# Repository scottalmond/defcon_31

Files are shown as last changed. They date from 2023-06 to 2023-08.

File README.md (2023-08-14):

# Space Pony Overview

This repo contains the project files for two Silly Add-On (SAO) Printed Circuit Boards (PCBs) for DEFCON 31.

## User Guide

Where to buy the units is explained here:

Bumper reel and general information (https://www.youtube.com/watch?v=0cRPfB8QzD0)

A summary of the key features and interfaces are documented in the following video:

Features and Interfaces (https://www.youtube.com/watch?v=cUO3zqiO3F0)

## Space Bits R Us

This is the team badge for those competing in the Hack-a-Sat competition.  These are exclusive badges for the team and not for general sale.

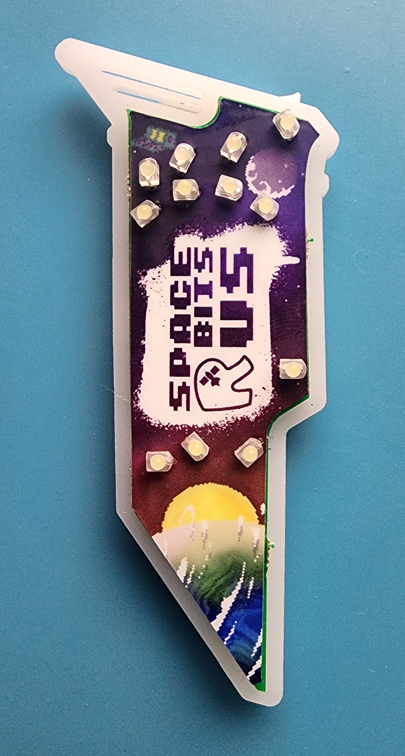
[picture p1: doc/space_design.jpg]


## Pony Circuit Board

- These badges present "My Little Pony Friendship is Magic" characters surrounded by LEDs.
- These badges are for sale, $20 per unit.  There are 11 unique designs.
- Each "Space Bits R Us" team member (identifiable because they are wearing the "Space Bits" badge described above) will have several units for sale.
- Visit the Hack-a-sat competition area immediately before, or immediately after competition each day to acquire one.
	- Specifically: ---before 10 AM Friday/Saturday---, after 8 PM Friday/Saturday, before Noon Sunday, or after 1:30 PM Sunday.
- Excess stickers were attached to colored acrylic for general distribution
	- Only white acrylic units have LEDs

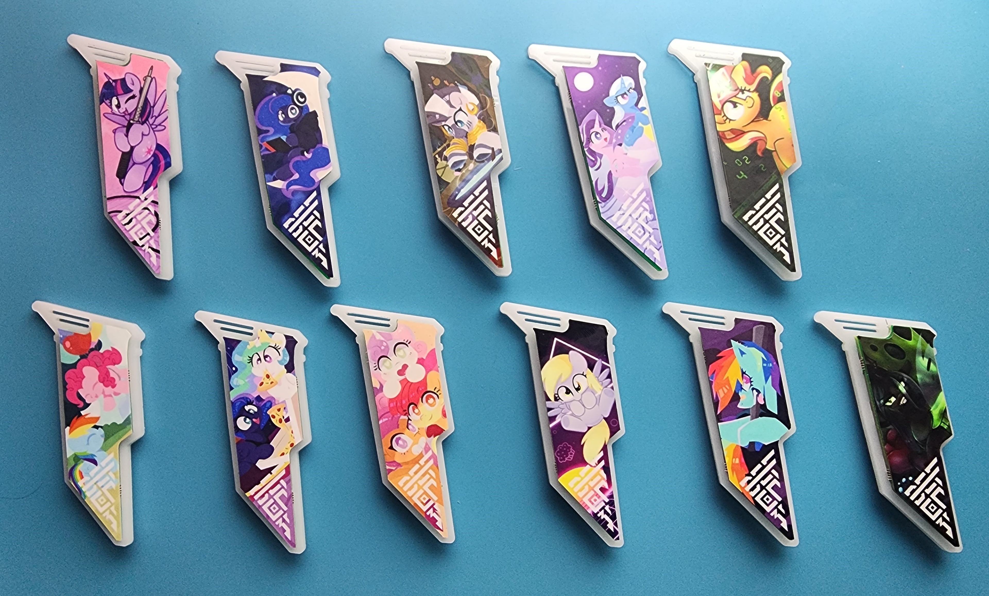
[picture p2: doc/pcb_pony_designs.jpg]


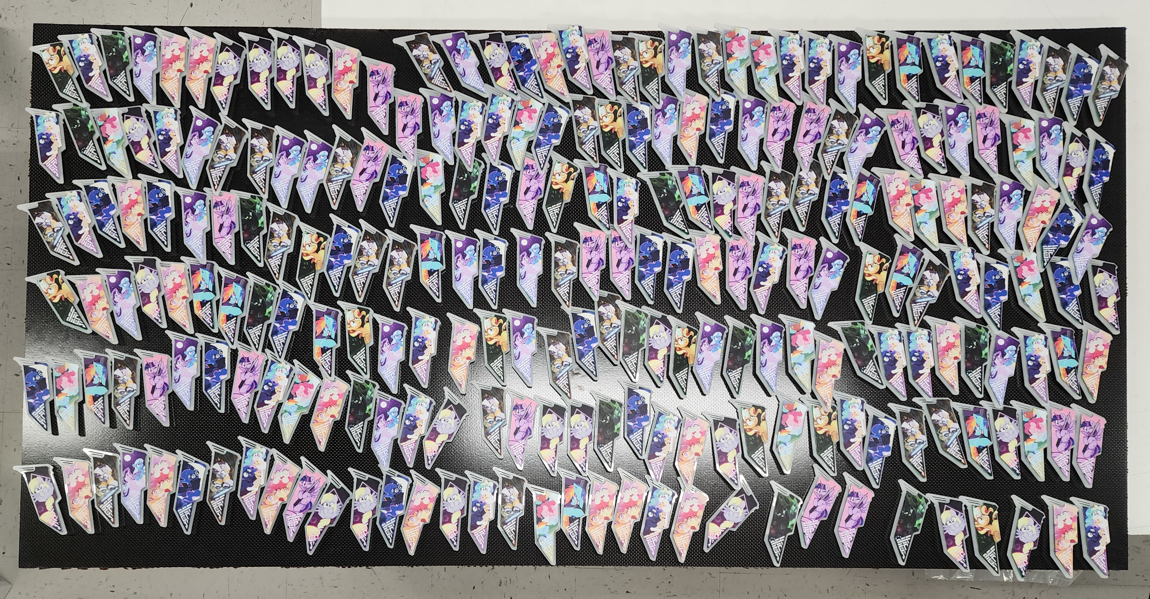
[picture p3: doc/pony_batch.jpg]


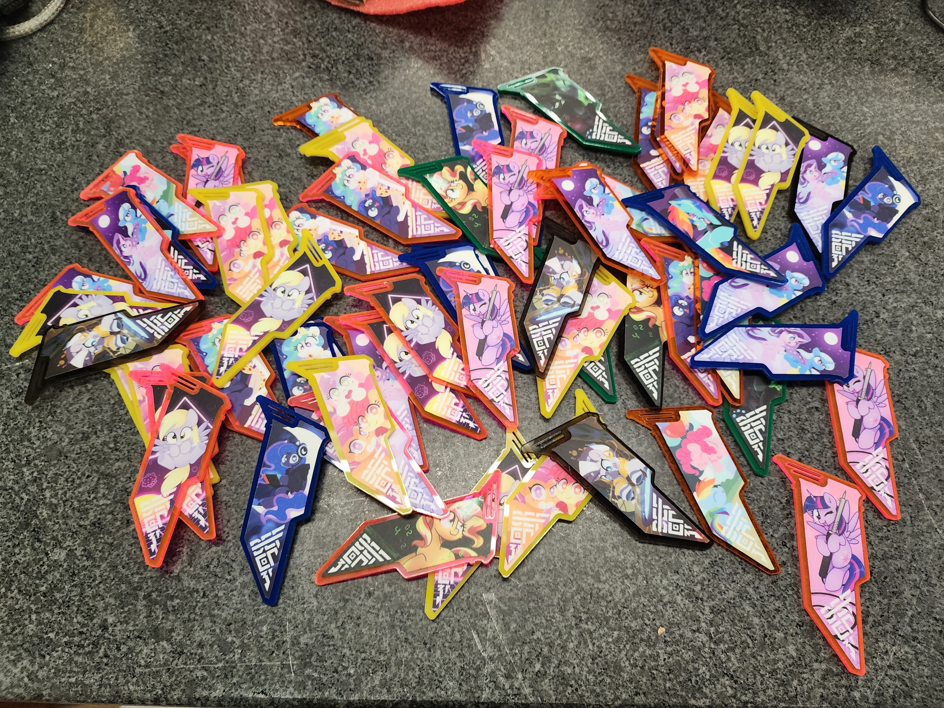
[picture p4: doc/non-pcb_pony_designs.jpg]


# Features

- STM8S003F3P6TR Processor
	- 8 kB Flash
	- 1 kB RAM
	- 128 B EEPROM
- Microphone
- 16 MHz clock, 10 ppm
- LiPo Battery
	- 40 mAh LIR2032 LiPo (Pony SAO)
		- ~2 hours battery life at max brightness
	- 500 mAh 502540 LiPo (Space Bits R Us SAO)
		- ~25 hours battery life at max brightness
- LiPo Charger
	- ~3 hours to charge from 3V to 4.2V
- Developer header
	- 5V charging input
	- ST SWIM Interface
	- 57600 MBaud UART
	- I2C
- SAO 4-pin header pads
	- Under BT1 (Pony SAO)
	- Under Acrylic (Space Bits R Us SAO)
- 10x RGB LEDs
- 12x White LEDs
	- Space Bits R Us SAO Only
- 1x Status LED
	- Green
		- 5V input is present
		- Battery is fully charged, if present
	- Green + Blue = Cyan
		- Battery Charging is Underway
	- Red
		- A user button is pressed, or UART terminal is active

# Schematic

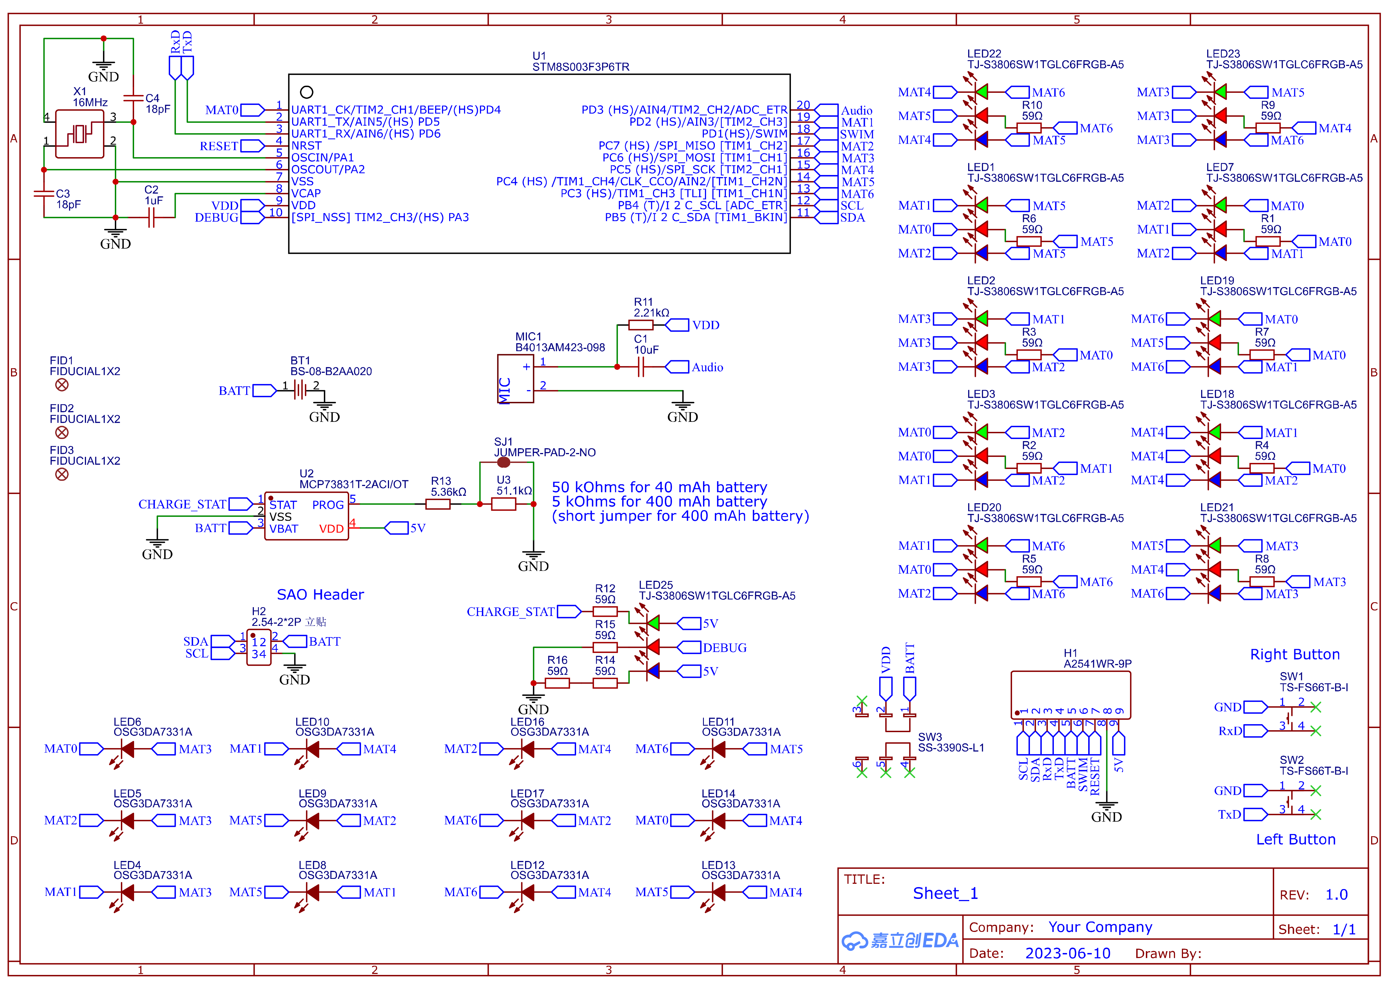
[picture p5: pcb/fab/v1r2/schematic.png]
DefCon31 v1r2


# Hardware

## Design

- Concept, Project Management, PCB Design, Software Architecture: [Scott Almond](https://github.com/scottalmond)
- Morse Code, Cyclone Game, Terminal Artwork: [Brian Wilkins](SpaceHamBrian@gmail.com)
- Pony & space artwork: [Sugar Morning](https://twitter.com/itssugarmorning)

## Fabrication & Tools

- PCB design in [EasyEDA](https://easyeda.com/); PCB/PCBA fabrication through [JLCPCB](https://jlcpcb.com/)
- Acrylic stock, 45% lighting white, 1/8" thick through [TAP Plastics](https://www.tapplastics.com/)
- Acrylic cutting in-house using a LC40 Dremel laser cutter
- Stickers fabricated by [Sticker Mule](https://www.stickermule.com/)
- Through-hole LEDs, batteries, and support hardware (protoboards, pogo pins, etc) purchased through [Aliexpress](https://www.aliexpress.us) vendors

# Eratta

- STM8 programming reference: https://hackaday.io/project/161239-stm8s-development-board
- STM8 programmer setup: https://circuitdigest.com/microcontroller-projects/getting-started-with-stm8s-using-stvd-and-cosmic-c-compiler
	- Including Cosmic C license request (allow 2 business days to get a key) ref. https://github.com/NevynUK/The-Way-of-the-Register
- How to fix git login: https://www.youtube.com/watch?v=EaN7TnD8RvM

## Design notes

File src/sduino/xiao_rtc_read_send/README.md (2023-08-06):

# SAMD21 Xiao Button Interface and DS3231 RTC Task

This Arduino code is designed to work with a SAMD21 Xiao microcontroller board, a Joystick Shield button interface, and a DS3231 Real-Time Clock (RTC) module. The code is intended to perform a specific task when the user presses a button on the Joystick Shield.

## Task Description

When the user presses the button on the Joystick Shield:

1. Turn on the on-board LED of the SAMD21 Xiao to indicate the start of the task.
2. Drive a digital output pin low to signal another board to go into developer mode.
3. Read the current time from the DS3231 RTC module and convert it to milliseconds since 8/5/2023 at midnight.
4. Create a time string in the format "t <milliseconds>\n" (e.g., "t 5649548\n").
5. Transmit the time string over UART (Serial) to the other board at a baud rate of 57600.
6. Optionally, introduce a small delay (100 milliseconds) to indicate the completion of the task.
7. Disable the relay by setting the digital output pin to an input mode (float the developer mode pin).
8. Turn off the on-board LED to signify the end of the task.

## Usage

1. Connect the Joystick Shield button interface and DS3231 RTC module to the appropriate pins on the SAMD21 Xiao board as described in the "Connections" section of this README.
2. Install the required `RTCLib` library in the Arduino IDE to work with the RTC module.
3. Upload the provided Arduino code (`main.ino`) to the SAMD21 Xiao using the Arduino IDE.
4. The code will run in an infinite loop, waiting for the button press. When the button is pressed, the specified tasks will be executed sequentially.

## Connections

### Joystick Shield Button Interface:

- Connect the GND (ground) pin of the Joystick Shield to any GND pin on the SAMD21 Xiao.
- Connect the VCC pin of the Joystick Shield to any 3.3V pin on the SAMD21 Xiao.
- Connect the signal (SIG) pin of the Joystick Shield to a digital input pin on the SAMD21 Xiao, for example, pin 2.

### DS3231 RTC Module:

- Connect the GND (ground) pin of the RTC module to any GND pin on the SAMD21 Xiao.
- Connect the VCC pin of the RTC module to any 3.3V pin on the SAMD21 Xiao.
- Connect the SDA pin of the RTC module to the I2C data pin (SDA) on the SAMD21 Xiao, usually pin A4.
- Connect the SCL pin of the RTC module to the I2C clock pin (SCL) on the SAMD21 Xiao, usually pin A5.

## Notes

- Replace `<outputPin>` in the code with the actual pin number you want to use for the developer mode signal.
- Ensure that the RTC module and Joystick Shield are connected properly to avoid any issues.
- The on-board LED will briefly illuminate during task execution, indicating that the task is in progress.

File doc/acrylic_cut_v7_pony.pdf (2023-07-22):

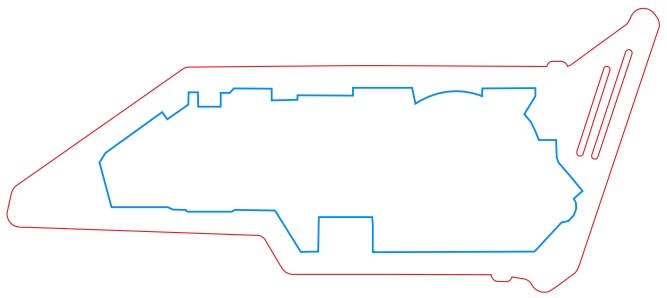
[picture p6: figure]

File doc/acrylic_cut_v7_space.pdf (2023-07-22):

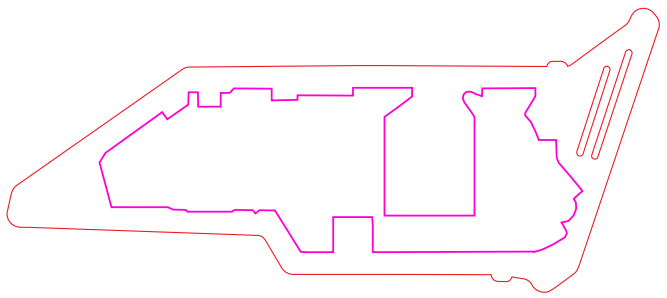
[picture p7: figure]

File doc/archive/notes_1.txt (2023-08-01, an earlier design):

void set_rgb(u8 led_index,u8 rgb_index,u8 brightness);// led_index[0-9], rgb_index[0-2], brightness[0-255]
void set_white(u8 led_index,u8 brightness);// led_index[0-11], brightness [0-255]
void set_debug(u8 brightness);
//void set_led_count(u8 led_count);//led_count [0-41] of non-zero illuminated RGB+White LEDs
void flush_leds(u8 led_count);//pushes the temprory values live to the periphreal
void reset_leds();//sets all rgb+white LEDs to 0 brightness
uint8_t get_audio();//sampling at 1-4 kHz, updating a state machine at 256 states (4-16 Hz updates)
//bool get_button(bool is_left);//return true if button is pressed.  does NOT perform de-bouncing
u32 millis();//returns a long value of the current time stamp (UNIX milliseconds since 1/1/1970)
bool delay(u16 milliseconds);//milliseconds to wait for.  returns true on success (completed wait operation).  returns false if wait was interrupted (ex. by button push)
bool is_space_bits();//returns true if the SAO is configered for the Space Bits team, otherwise returns false for the 
char readEEPROM(u8 address);//fetch value from EEPROM
void writeEPROM(u8 address,u8 value);//push value into EEPROM
bool is_button_pressed(bool is_left,bool is_short); //isButtonPressed(true,true); returns true if the left button is pressed for 0.05-2 seconds.  (true,false) returns true if left button has been pressed for >2 seconds.  so bool is_right=isButtonPressed(false,true) || isButtonPressed((false,false); is expected here
void clear_button_pressed(bool is_left,bool is_short); //call this after you consume/use or otherwise respond to a button press event
bool is_application_valid(); //when you do infinite while(true) loops, use this method for the "true" part.  I'll be polling for console UART content and timeouts here.  When there are external events, this method will return false and the submenu will exit up to the top level menu.

//UART:
//t # //get time with no parameters, set time with one decimal number.
//  u# //DEPRECITED, was going to used to correct sub-second clock drivt residual; assumed to be negliable and low-priority
//e # # //write to eeprom directly.  numbers are in human-readable DEC (not 0-255 in every char; this avoid issue with 10 being read as '\n')
//e # //read eeprom char at address
//h help (prints epprom status and current time)
//p ping (echo's UART commands sent to it: between 'p' character and \n)
//  s# system diagnostic (test all peripherals: blink leds, read audio and output to terminal: 1k samples).  diagnostic 0 is all leds and mic check.  diagnsotic 1 is current time (millis()/1000): the 10 LSB piped out to RGB LEDs
//l # # # //light up the given RGB led at the given brightness (0-9, 0-2, 0-255)
//w # # //light up the given white led at the given brightness (applicable to Space SAO only, others will have current leakage on red+green LEDs over non-populated part)
//a //prints the audio level continuosuly until a new line character is detected

//EEPROM:
//0 DEVELOPMENT
//1 TEST (sw revision id)
//2 Space Bits (1 for team, 0 for cute sales)
//3 DEVICE ID
//4-7 baseline start ms
//8-11 time base ms
//12 +/- 1 ms

//diagnostic menu: the LSB 10 bits of the current time (millis()/1000) are mapped to the RGB around the periphery.  When time is syncronized, across all badges, they all tick-tock in unison

void t()
{
	eeprom.write(4:7,UART.read());
	tms=0;
}

void u()
{
	u16 diff_residual=tms-UART.read();//how far off time-at-tone was from expectation
	long diff_baseline=UART.read()-eeprom.write(4:7);
	diff_baseline/=diff_residual;
	eepromt.write(8:11,diff_baseline<0?-diff_baseline:diff_baseline);//write positive number to flash
	eeprom.write(diff_baseline<0?-1:1);
}

#define RGB_LED_COUNT 9
#define WHITE_LED_COUNT 11

rules:
- for digital read/write, must use the methods above
- in order to use a variable, must declare at the beginning of a method
- types: int (signaed 16-bit), char/uint8_t unsigned 0-255, long (4-byte), bool

menus

sudo sode for audio:
void submenu_audio()
{
	u8 audio_level,led_index;
	audio_level=get_audio();
	reset_leds();
	for(led_index=0;led_index<RGB_LED_COUNT;led_index++)
	{
		if(audio_level/4>led_index)
		{
			if(led_index<6) set_rgb(led_index,1,255);
			else if(led_index<6) set_rgb(led_index,1,255);
			else(led_index<6) set_rgb(led_index,1,255);
		}
	}
	set_led_count(12);//6 greens, 2 yellows (green+red), 2 reds
	flush_leds();
}

//PRECON: when entering a submenu, the millis() is recorded in submenu_start_tms
//u32 submenu_millis();//returns the millisconds since starting this submenu

void top_menu()
{
	while(1):
	{
		//buttons state stuff...
		switch(submenu_index)
		{
			case  0:
			{
				
			}
			case 1:
			{
				display_only_morse();
			}
		}
	}
}

//given millis9), determine what frame content to display (single frame)
void display_only_morse(bool is_first_call)
{
	u8 is_dit_dah;
	reset_leds();
	char str="space bits";//PRECON lower case
	u32 millis_elapsed=millis()-submenu_start_millis;
	is_dit_dah=get_morse_state(str,millis_elapsed,300);
	switch(is_dit_dah)
	{
		case 1://display a dit pattern
			//set leds 5-9 blue
		{
			
		}
		case 2:
		{//display a dah pattern
			//set leds 0-4 green
		}
		default:{}//off
	}else{
		
	}
}

//numbers 5 did/das
//number 0-9, 'a' at 10 .. 'z' at 35
//3 LSB are the number of dah/dits (morse[N] & 0x07 = 3 LSB's: a value between 0 and 5)
//5 MSB are the dah (1), dit (0)
//bits 0-2 are the count of dah dits
//bit 3 is the first dih/dah, bit 7 is the last one
const u8 morse[36]={0b01110100,0b00110011};

/**
 * The given code is a function that determines the state of a Morse code LED
 * based on a string and a specific moment in time.
 * 
 * Allowable characters: 'a-z', '0-9', ' ', and '\0'
 * No capital characters are allowed
 *
 * @param array The input string
 * @param millis_elapsed The time elapsed in milliseconds
 * @param timebase_millis The base time for each Morse code element
 * @return 0 if LED is OFF; 1 is a dit, 2 if dah              
 */
u8 get_morse_state(char array[], u32 millis_elapsed, u16 timebase_millis)
{
	u8 char_index=0;
	
	// Stores the compressed representation of the Morse code (3 bits for the 
	// count and 5 bits for pattern)
	u8 dah_dit_compressed=0; 
	
	u8 dah_dit_count=0;
	u8 dah_dit_index=0;
	u32 offset_tms=0;
	
	while(array[char_index] != '\0')
	{
		if(array[char_index] != ' ')
		{
		    // Retrieves the compressed Morse code representation for the current character.
			// The code uses a lookup table called morse to obtain the Morse code pattern.
			// Manipulation of ASCII values allows the code to convert characters into suitable
			// indices for retrieving the Morse code count and compressed pattern from the lookup
			// table.
			dah_dit_count = morse[array[char_index]<='9'?array[char_index]-'0':(array[char_index]-'a'+10)]&0x07;
			dah_dit_compressed = morse[array[char_index]<='9'?array[char_index]-'0':(array[char_index]-'a'+10)]>>3;
		}
		// ternary operatior for number vs character
		for(dah_dit_index=0;dah_dit_index<dah_dit_count;dah_dit_index++)
		{
			offset_tms += timebase_millis*((dah_dit_compressed&0x01)?3:1);
			if(offset_tms>millis_elapsed) return 1+(dah_dit_compressed&0x01);
			offset_tms += timebase_millis;
			if(offset_tms>millis_elapsed) return 0;
			dah_dit_compressed = dah_dit_compressed>>1;
		}
		offset_tms += timebase_millis*2;
		if(offset_tms>millis_elapsed) return 0;
		if(array[char_index]==' ')
		{
			offset_tms += timebase_millis*4;
			if(offset_tms>millis_elapsed) return 0;
		}
		char_index++;
	}
	return 0;
}

//period

//void set_led_count(u8 led_count);//led_count [0-41]

u8 sleep_amount=250;//max sleep duration before wrap-over occurs
bool buffer_index=pwm_state&0x01;//primary vs rendant side to pull data from

if(pwm_sleep_remaining>0)
{//if sleep remaining, keep sleeping

}else if(pwm_led_index<pwm_led_count)
	setMatrixHighZ();
	setLED(pwm_brightness[pwm_led_index][0][buffer_index]);
	pwm_sleep_remaining=pwm_brightness[pwm_led_index][1][buffer_index];
	pwm_led_index++;
}else{
	setMatrixHighZ();
	pwm_led_index=0;
	pwm_sleep_remaining=pwm_sleep[buffer_index];
	if(pwm_state&0x02) pwm_state^=0x03;//if flag to swap A/B is set, then clear the flag and swap sides
}
sleep_amount=pwm_sleep_remaining<sleep_amount?pwm_sleep_remaining:sleep_amount;
pwm_sleep_remaining-=sleep_amount;

TIM3->CCR1L = ( (TIM3->CCR1L) + sleep_amount )%250;

u8 main()
{
	while(1)
	{
		display_morse();
	}
}

//returns 0 for OFF, 1 for dit, 2 for dah
u8 display_morse()
{
	u8 dih_vs_dah,iter;
	u8 morse_space[]={0x01011101, 0x11010001, 0x01110001, ... }; // <-- fill in this part ("SPACE BITS R US" or similar) left to right with info about just whether leds should be on or off, no compression.  dit is a '1', dah is '111'
	//PARIS: 0 1 0 111 0 111 0 1 000 1 0 111 000 1 0 111
	//={0x01011101,0x11010001,0x01110001,0x0111... }
	//pad with 0s at the end as needed to fill in the final byte
	//PRECON: the MSB on the first byte shall be 0
	u8 morse_defcon[]={0x01011101, 0x11010001, 0x01110001, ... }; // <-- fill in this part for "DEFCON31"
	u16 sizeof_morse_list=is_space_sao()?sizeof(morse_space):sizeof(morse_defcon);
	dih_vs_dah=get_morse(is_space_sao()?morse_space:morse_defcon,sizeof_morse_list);
	for(iter=0;iter<WHITE_LED_COUNT;iter++)
	{
		if((dih_vs_dah==1 && dih_vs_dah&0x01) || dih_vs_dah==2)
		{//dih is every other LED ON, dah is all LEDs ON for longer time
			if(iter<RGB_LED_COUNT) set_rgb(iter,2,255);
			if(is_space_sao()) set_white(iter,255);
		}
	}
	flush_leds(WHITE_LED_COUNT+RGB_LED_COUNT+1);
}

//return 0 for OFF, dih as 1, or dah as 2
u8 get_morse(u8 *morse_list,u16 sizeof_morse_list)
{
	u16 morse_cycle=0x0008;//period of the morse code cycling in lengths of *units* (there are dead bands at the end of each cycle while the patterns waits to repeat - needs to be an even multiple of 2 to make the clock math easy
	u16 morse_shift=sizeof_morse_list;//number of *bytes* in morse_list
	while(morse_shift)
	{
		morse_cycle<<=1;
		morse_shift>>=1;
	}
	u16 morse_bit=(millis()>>6)&(morse_cycle-1);//>>6 reduces speed (64 ms per unit) to around 20 wpm.  &val makes this periodic every morse_cycle
	bool is_dit=get_morse_unit(morse_bit,&morse_list,sizeof_morse_list);
	bool is_dah_ish=get_morse_unit(morse_bit-1,&morse_list,sizeof_morse_list)||get_morse_unit(morse_bit+1,&morse_list,sizeof_morse_list);
	return is_dit+(is_dit&is_dah_ish);//0 if !is_dit.  1 if is_dit, but neither neighbor is ON.  2 if morse_bit is ON and at least one neighbor is too
}

//returns 1 if the LEDs should be ON at the given morse_bit, returns 0 if LEDs should be OFF
bool get_morse_unit(u16 morse_bit,u8 (*morse_list),u16 sizeof_morse_list)
{
	//if(morse_bit==0xFFFF) return 0;//value at index -1 --> save a line of code: PRECON is that morse_list shall have 0 as MSB on first byte, so the value at [-1] is undefined and also doesn't matter
	u16 morse_index=morse_bit>>3;//get the byte-wise index within the array
	if(morse_index>=sizeof_morse_list) return 0;
	u8 morse_shift=morse_bit&0x07;//3 LSBs are which bit within the byte to fetch
	return (*morse_list)[morse_index]>>(7-morse_shift)&0x01;//use "7-" to make it easier to generate and read the list constructor left-to-right
}

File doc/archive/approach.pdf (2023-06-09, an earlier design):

# DEFCON 31 SAO

# - Market Research - SWAP-CR - Approach

# Market Research

# - Silly Add Ons (SAO) have been made for other conventions

## – #badgelife – Often use Light Emitting Diodes (LEDs) and Printed Circuit Boards (PCBs) – Most have 2*2 or 2*3 100 mil header to collect power from the host badge

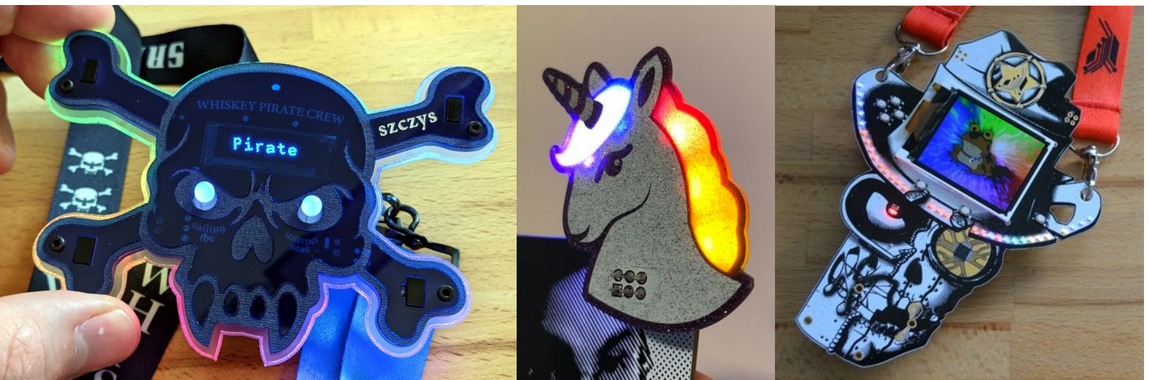
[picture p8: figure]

# Market Research

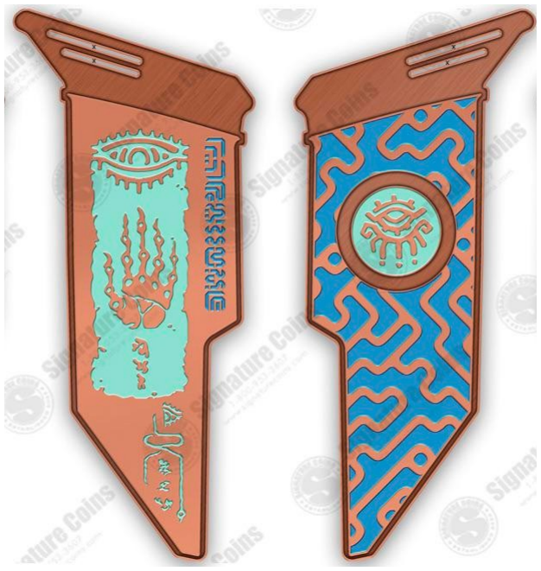
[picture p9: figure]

## - Specs posted May 17

## – https://media.defcon.org/DEF%20CON%2031/D EF%20CON%2031%20badge/ (https://media.defcon.org/DEF%20CON%2031/DEF%20CON%2031%20badge/)

- Svg board outline
- Blender File shell
– Cleaned up for 3D print here:
- https://www.thingiverse.com/thing:6060558

## - Limited time (June 9 as of writing) for designs to appear online

## – One example -->

- https://www.reddit.com/r/Defcon/comments/13yoc96/
my_final_proof_submitted_for_release_to_pressing/

# Size

### - SAO slides into the (provided) clam

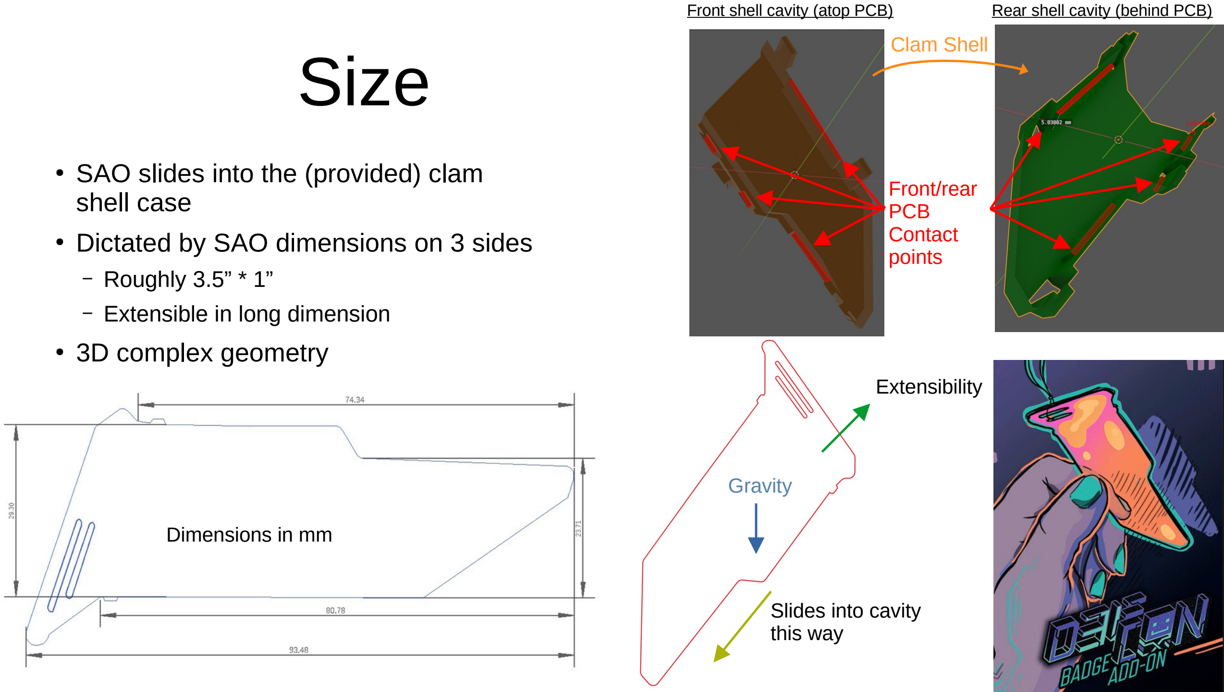
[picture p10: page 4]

### shell case - Dictated by SAO dimensions on 3 sides

– Roughly 3.5” * 1”
– Extensible in long dimension

### - 3D complex geometry

Gravity

Dimensions in mm

Extensibility

Rear shell cavity (behind PCB)

Slides into cavity
this way

Front shell cavity (atop PCB)
Clam Shell

Front/rear
PCB
Contact
points

1.08 mm

# Weight

# - Bulk (>50%) of weight will come from battery

# – 9 grams for 400 mAh (<0.02 lb) – http://www.ibt-power.com/Battery_packs/Li_Polymer

/Lithium_polymer_cells.html (http://www.ibt-power.com/Battery_packs/Li_Polymer/Lithium_polymer_cells.html)

# – Assumed to be a non-issue

# - Expecting badge to weigh notably more than SAO

# Power

## - Cavity behind badge is roughly 5mm deep

## – Roughly 26.5 mm “wide” and 38m “tall” – LiPo battery naming is DDWWHH, in mm, where depth omits decimal place

### - ex. Common CR2032 dime cell is 20 mm diameter and 3.2 mm deep - LP452530, 420 mAh

– https://www.lipobattery.us/lipo-battery-lp452530-3-7v-310mah-with-protection-circuit-and-wires-15mm/

## – LiPos charge at 0.5C: 0.5*capacity per hour: 200 mAh/hour

### - Most LiPos take 2 hours to charge fully, regardless of size

## - 400 mAh/(10-hour day) = 40 mA continuous

## – LEDs draw 5-20 mA, so enough for 2 bright LEDs, or many dim ones

# Cost

## - Prototype

### – Qty 5: $

## - Space

### – Qty 50: $

## - Pony

### – Qty 300: $ – Assuming sales (~$20) to 1% of DEFCON attendees

## - Sum

### – All: $ – Per person: $

# Eratta

- Note: Only the front side of the SAO will be visible – The rear will be obscured by a battery, electronics and the rear of the badge
- The long dimension does not align with gravity, the SAO hangs crooked
- DEFCON 31 badge is un-powered. SAOs need to provide their own power
- The nubs on either side of the PCB interlock with divets in the case.
– Aside from gravity, this is the only mechanism preventing the SAO from jumping out of the badge – NOTE: The divets only extend for 3 mm (measured from the front face) of the 4.8 mm SAO depth. Any design leveraging these slip fit points cannot be more than 3 mm thick here

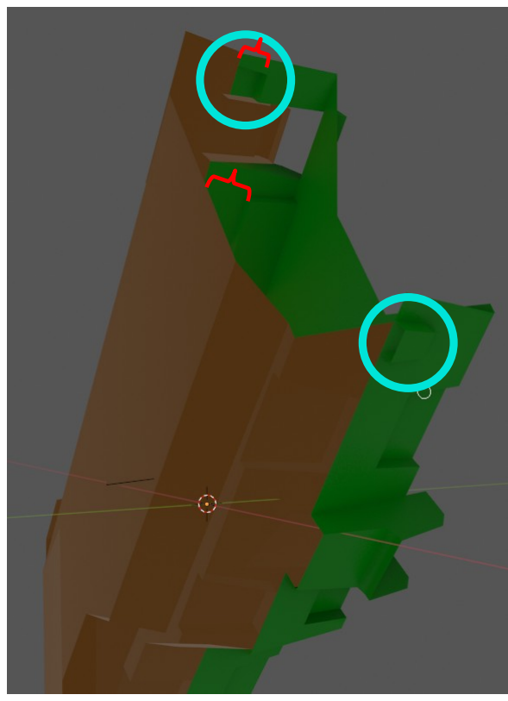
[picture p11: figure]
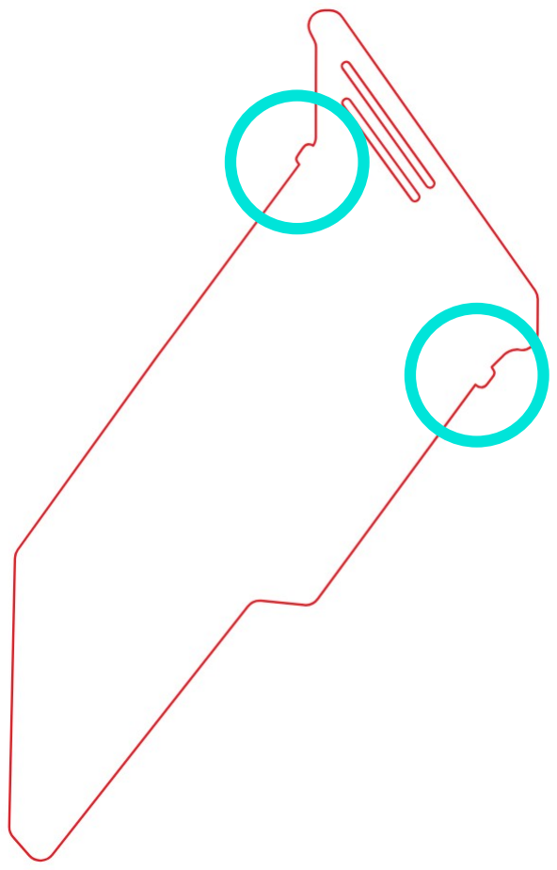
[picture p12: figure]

# Approach: Depth/Stack-up

# - 2-layer PCB

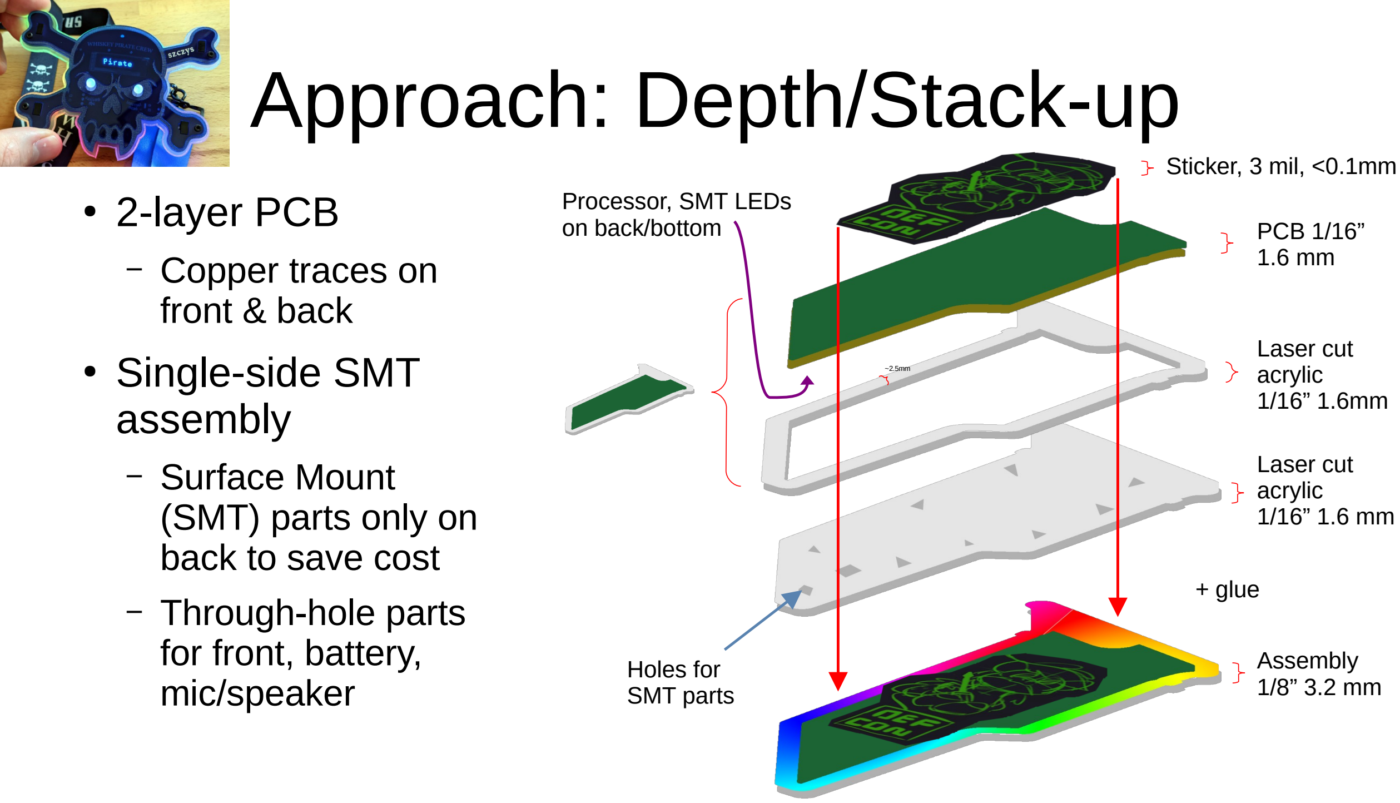
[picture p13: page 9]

## – Copper traces on front & back

# - Single-side SMT assembly

## – Surface Mount (SMT) parts only on back to save cost – Through-hole parts

for front, battery,

## mic/speaker

PCB 1/16”
1.6 mm

Laser cut
acrylic
1/16” 1.6mm

Laser cut
acrylic
1/16” 1.6 mm

Assembly
1/8” 3.2 mm

Holes for
SMT parts

Sticker, 3 mil, <0.1mm
Processor, SMT LEDs
on back/bottom

+ glue

~2.5mm

# Pony Art Canvas

# Sales

# - Each team member is given several badges in exchange for $TBR

# – 1x space badge – ~6x pony badges (~4x LED powered, ~2x un-powered acrylic)

# - The assumption being the team member will sell at least one before and after each event day (on average)

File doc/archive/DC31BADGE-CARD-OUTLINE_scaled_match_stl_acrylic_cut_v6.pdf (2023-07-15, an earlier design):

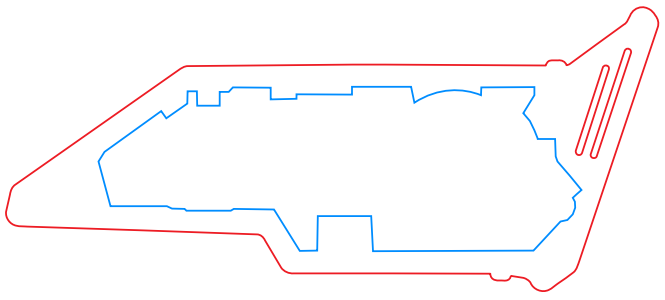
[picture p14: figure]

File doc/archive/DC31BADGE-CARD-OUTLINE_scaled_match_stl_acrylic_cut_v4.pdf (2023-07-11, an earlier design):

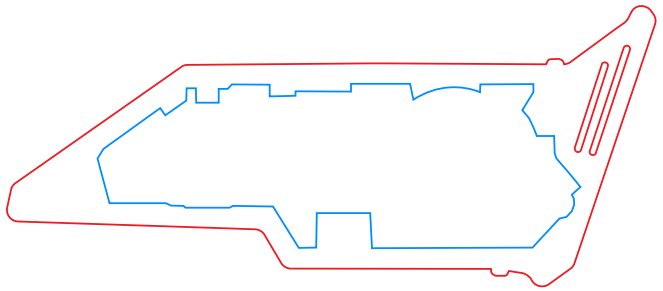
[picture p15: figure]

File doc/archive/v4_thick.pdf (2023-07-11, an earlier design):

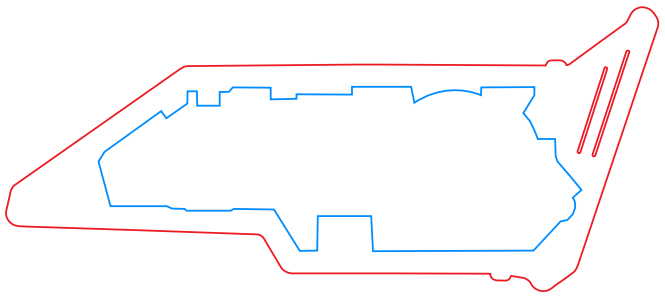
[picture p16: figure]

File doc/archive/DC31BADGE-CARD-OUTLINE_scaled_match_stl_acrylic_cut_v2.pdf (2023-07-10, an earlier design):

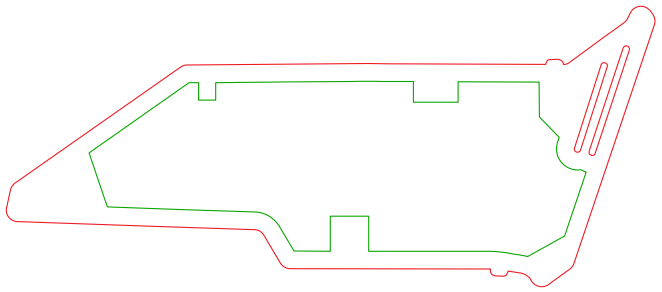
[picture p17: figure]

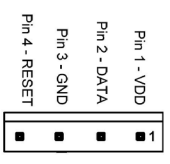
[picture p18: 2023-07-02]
doc/pinout_1.png

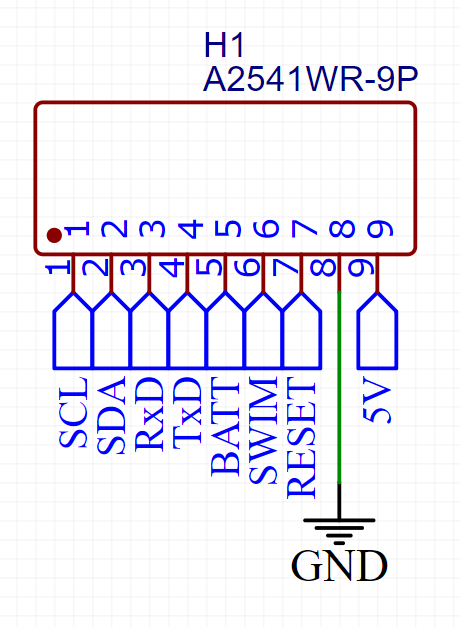
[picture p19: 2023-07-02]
doc/pinout_2.png

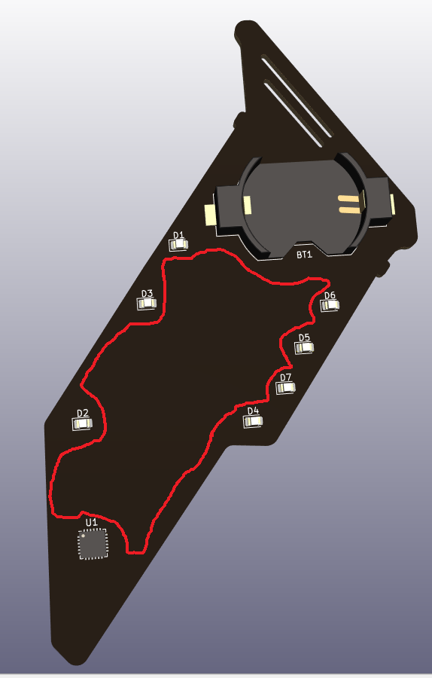
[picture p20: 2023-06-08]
doc/ideas_space_bits/img/delete_me4.png

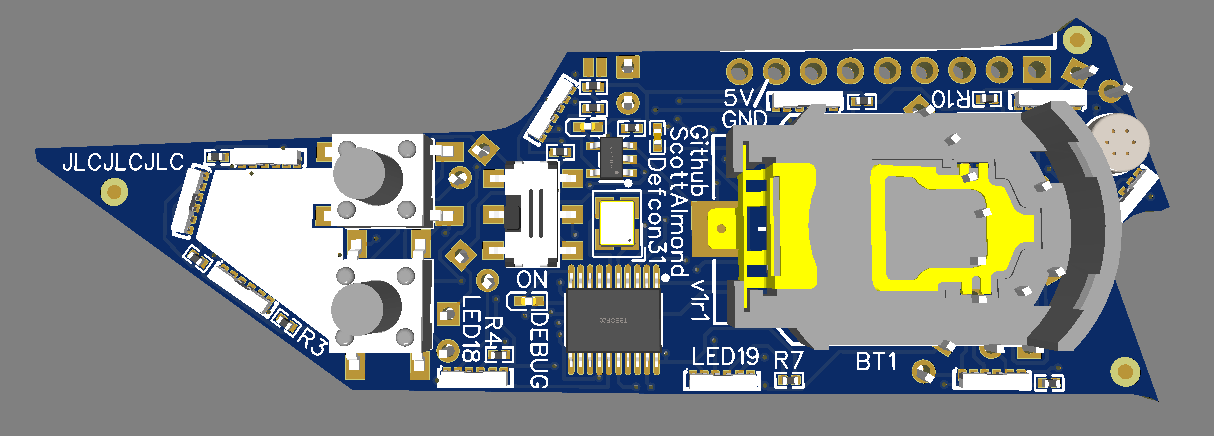
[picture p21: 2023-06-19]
doc/ideas_space_bits/img/draft_4r.png

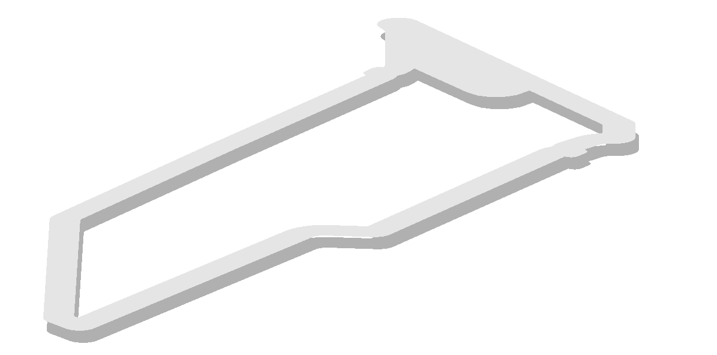
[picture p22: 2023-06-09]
doc/ideas_space_bits/img/rainbow_acrylic.png

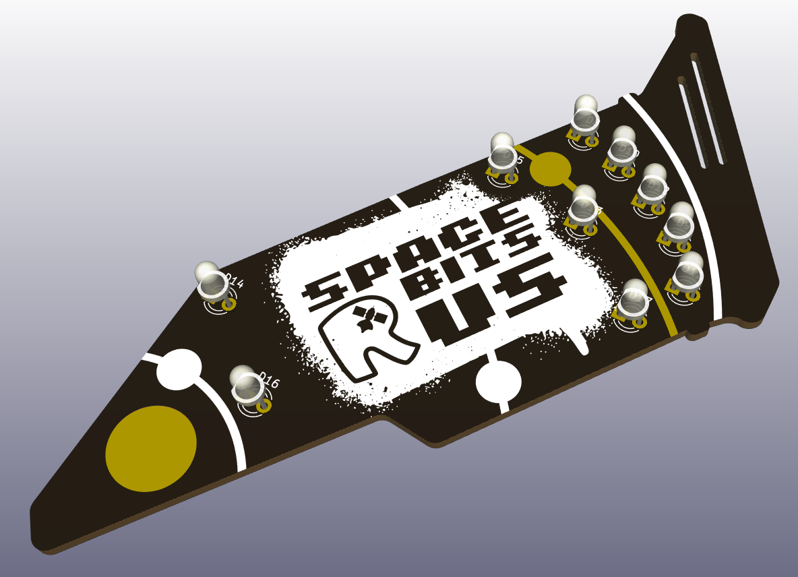
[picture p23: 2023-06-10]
doc/ideas_space_bits/img/render_1.png

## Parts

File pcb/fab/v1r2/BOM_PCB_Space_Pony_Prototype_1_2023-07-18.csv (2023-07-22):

ID | Name | Designator | Footprint | Quantity | Manufacturer Part | Manufacturer | Supplier | Supplier Part | Price
1 | 5.36kΩ | R13 | R0402 | 1 | CR0402FF5361G | LIZ(丽智电子) | LCSC | C100471 | 0.001
2 | 51.1kΩ | U3 | R0402 | 1 | MCR01MZPF5112 | ROHM(罗姆) | LCSC | C509676 | 0.005
3 | B4013AM423-098 | MIC1 | MIC-SMD_BD4.0_B4013AM423-098_WIDER_TRACE_CLEARANCE | 1 | B4013AM423-098 | Goertek(歌尔) | LCSC | C2835889 | 0.154
4 | MCP73831T-2ACI/OT | U2 | SOT-23-5_L3.0-W1.7-P0.95-LS2.8-BL | 1 | MCP73831T-2ACI/OT | MICROCHIP(美国微芯) | LCSC | C424093 | 0.743
5 | TJ-S3806SW1TGLC6FRGB-A5 | LED18,LED19,LED20,LED21,LED22,LED23,LED7,LED1,LED2,LED3,LED25 | LED-SMD_6P-L4.5-W1.0_TJ-S3806SW1TGLC6F | 11 | TJ-S3806SW1TGLC6FRGB-A5 | TOGIALED(统佳) | LCSC | C601694 | 0.118
6 | STM8S003F3P6TR | U1 | TSSOP-20_L6.5-W4.4-P0.65-LS6.4-BL | 1 | STM8S003F3P6TR | ST(意法半导体) | LCSC | C52717 | 0.586
7 | TS-FS66T-B-I | SW1,SW2 | KEY-SMD_4P-L6.1-W6.1-P4.50-LS9.0 | 2 | TS-FS66T-B-I | XKB Connectivity(中国星坤) | LCSC | C500114 | 0.149
8 | BS-08-B2AA020 | BT1 | BAT-SMD_BS-08-B2AA016 | 1 | BS-08-B2AA020 | MYOUNG(美阳) | LCSC | C964786 | 0.331
9 | 59Ω | R1,R2,R3,R4,R5,R6,R7,R8,R9,R10,R12,R14,R15,R16 | R0402 | 14 | RTT0259R0FTH | RALEC(旺诠) | LCSC | C159005 | 0.001
10 | SS-3390S-L1 | SW3 | SW-SMD_6P-P2.50_L3.5-W7.2 | 1 | SS-3390S-L1 | XKB Connectivity(中国星坤) | LCSC | C318998 | 0.109
11 | 2.21kΩ | R11 | R0402 | 1 | CR0402FF2211G | LIZ(丽智电子) | LCSC | C100313 | 0.001
12 | 10uF | C1 | C0402 | 1 | GRM155R60J106ME05D | muRata(村田) | LCSC | C723895 | 0.017
13 | 1uF | C2 | C0402 | 1 | CL05B105KQ5NQNC | SAMSUNG(三星) | LCSC | C307427 | 0.007
14 | 18pF | C3,C4 | C0402 | 2 | FN15N180J500PNG | PSA(信昌电陶) | LCSC | C363512 | 0.002
15 | 16MHz | X1 | OSC-SMD_4P-L3.2-W2.5-BL | 1 | 7V16000001 | TXC Corp | LCSC | C331581 | 0.166

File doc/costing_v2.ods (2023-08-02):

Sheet: Sheet1
Cost Model |  |  |  | Prototype |  |  |  | Production |  |  |  |  | As-built
Item | Part Number | Reference Designator | URL | Boards | Qty/board | Unit Cost | Extended Cost | Boards | Qty/board | Unit Cost | Extended Cost |  | Vendor | Description | Dollars | Date
RGB LED | TJ-S3806SW1TGLC6FRGB-A5 |  | https://jlcpcb.com/partdetail/Togialed-TJ_S3806SW1TGLC6FRGBA5/C601694 | 5 | 10 | $0.11 | $5.72 | 300 | 11 | 0.0933 | 307.89 |  | Artist |  | 1000 | 06/10/23
SMT LED (blue) | BL-HB337A-AV-TRB |  | https://jlcpcb.com/partdetail/177360-BL_HB337A_AVTRB/C165977 | 5 | 2 | 0 | 0 | 300 | 2 | 0.0154 | 9.24 |  | JLC | BOM 1 | 602.32 | 06/13/23
Processor | STM8S003F3P6TR |  | https://jlcpcb.com/partdetail/Stmicroelectronics-STM8S003F3P6TR/C52717 | 5 | 1 | 0.5992 | 2.996 | 300 | 1 | 0.3923 | 117.69 |  | JLC | Prototype | 71.12 | 06/18/23
LiPo Charger | MCP73831T-2ACI/OT |  | https://jlcpcb.com/partdetail/MicrochipTech-MCP73831T_2ACIOT/C424093 | 5 | 1 | 0.7088 | 3.544 | 300 | 1 | 0.4587 | 137.61 |  | JLC | BOM 2 | 171.61 | 06/18/23
Power Switch | SS-3390S-L1 |  | https://jlcpcb.com/partdetail/XkbConnectivity-SS_3390SL1/C318998 |  |  |  | 0 | 300 | 1 | 0.0829 | 24.87 |  | Aliexpress | LiPOs and Thru hole LEDs | 292.28 | 06/18/23
button | TS-FS66T-B-I |  | https://jlcpcb.com/partdetail/XkbConnectivity-TS_FS66T_BI/C500114 |  |  |  | 0 | 300 | 2 | 0.1082 | 64.92 |  | Aliexpress | Pogo pins and breadboards | 36.47 | 06/21/23
Crystal | XXHBBCNANF-16.000000MHZ |  | https://jlcpcb.com/partdetail/TaitienElec-XXHBBCNANF_16000000MHZ/C521590 | 5 | 1 | 0.1291 | 0.6455 | 300 | 1 | 0.093 | 27.9 | v1r1 | Sticker Mule | Stickers | 36.38 | 07/04/23
Low CL crystal (8 pF) | 7V16000001 |  | https://jlcpcb.com/partdetail/TxcCorp-7V16000001/C90927 |  |  |  | 0 | 300 | 1 | 0.0759 | 22.77 |  | Aliexpress | LiPOs | 100.49 | 07/06/23 | Misread order qty (WAS qty 25, SHOULD BE qty 25)
microphone | B4013AM423-098 |  | https://jlcpcb.com/partdetail/Goertek-B4013AM423098/C2835889 | 5 | 1 | $0.15 | $0.75 | 300 | 1 | 0.1092 | 32.76 |  | JLC | BOM 3 | 58.15 | 07/09/23 | Updated BOM with revised LEDs
Battery Holder | BS-08-B2AA020 |  | https://jlcpcb.com/partdetail/Myoung-BS_08B2AA020/C964786 | 5 | 1 | 0.3214 | 1.607 | 300 | 1 | 0.2306 | 69.18 |  | TAP | Production Acrylic | 187.68 | 07/15/23 | 1 spare sheet to accommodate errors if needed, or spares
 |  |  |  |  |  |  | 0 |  |  |  | 0 |  | Sticker Mule | Production Space Stickers | 36.38 | 07/15/23
PCB |  |  |  | 1 | 1 | 2 | 2 | 1 | 1 | 82.7 | 82.7 |  | JLC | Production | 465.67 | 07/18/23
PCBA |  |  |  | 1 | 1 | 57.62 | 57.62 | 1 | 1 | 199.53 | 199.53 |  | JLC | Production Pony Stickers | 202.86 | 07/21/23
Tax & Shipping |  |  |  | 1 | 1 | -3.755 | -3.755 | 1 | 1 | 183.44 | 183.44
Customs |  |  |  |  |  |  | 0 | 1 | 1 | 125.79 | 125.79
 |  |  |  |  |  |  | 0 |  |  |  | 0
Dime Battery | LIR2032 |  | https://www.aliexpress.us/item/3256802521279926.html |  |  |  | 0 | 1 | 1 | 163.23 | 163.23
THT LED | 1.8mm |  | https://www.aliexpress.us/item/3256801898453742.html |  |  |  | 0 | 1 | 1 | 28.56 | 28.56
Flat Battery | 502540 | 500mAh | https://www.aliexpress.us/item/2255800864454094.html |  |  |  | 0 | 2 | 1 | 100.49 | 200.98
Protoboard |  |  |  |  |  |  | 0 | 1 | 1 | 36.47 | 36.47
Pogo Pins |  |  |  |  |  |  | 0 |  |  |  | 0
Tax & Shipping |  |  |  |  |  |  | 0 |  |  |  | 0
 |  |  |  |  |  |  | 0 |  |  |  | 0
Super glue |  |  |  |  |  |  | 0 | 2 | 1 | 8.5 | 17
Acrylic | 45% Lighting White, 1/8”, 12*20” |  | https://www.tapplastics.com/product/plastics/cut_to_size_plastic/acrylic_sheets_color/341# | 2 | 1 | 2 | 4 | 10 | 1 | 15.42 | 154.2
Tax & Shipping |  |  |  | 1 | 1 | 10.81 | 10.81 | 1 | 1 | 33.48 | 33.48
 |  |  |  |  |  |  | 0 |  |  |  | 0
Art |  |  |  |  |  |  | 0 | 1 | 1 | 1000 | 1000
Stickers | 4*6”, 8.5*11” |  | https://www.stickermule.com/products/sticker-sheets | 2 | 1 | 33 | 66 | 1 | 1 | 175 | 175
Tax & Shipping |  |  |  | 2 | 1 | 3.38 | 6.76 | 1 | 1 | 27.86 | 27.86
 |  |  |  |  |  |  | 0 |  |  |  | 0
Lanyard |  |  |  |  |  |  | 0 |  |  |  | 0
Tax & Shipping |  |  |  |  |  |  | 0 |  |  |  | 0
Subtotal |  |  |  |  |  |  | 158.69 |  |  |  | 3243.07
Collected |  |  |  |  |  |  | 3401.76
Attendees |  |  |  |  |  |  | 40
Total |  |  |  |  |  |  | 85.044

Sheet: Sheet2
vibration motor
microUSB
 | https://jlcpcb.com/partdetail/Xfcn-MF254VS_11_06PA/C492238
 | https://jlcpcb.com/partdetail/3092102-X1311WVS_04JC18D42R2/C2881610
 | uP draws 4.3 mA

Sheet: archive2
TSSOP-20 | header | pin | allocation
 |  | 1 | audio input | analog input
 | * | 2 | Button | TxD | Pull-up
 | * | 3 | Button | RxD | Pull-up
 | * | 4 | Reset
 |  | 5 | Crystal
 |  | 6 | Crystal
 | * | 7 | GND
 |  | 8 | VCAP
 | * | 9 | VDD
 |  | 10 | Debug_LED
 | * | 11 | SDA | drain only, 2MHz, weak |  | need external pull
 | * | 12 | SCL | drain only, 2MHz, weak |  | need external pull
 |  | 13 | LED
 |  | 14 | LED
 |  | 15 | LED
 |  | 16 | LED
 |  | 17 | LED
 | * | 18 | SWIM | PPS
 |  | 19 | LED
 |  | 20 | LED
 | 5V
 |  |  | TxD/RxD
 |  |  | I2C
 |  |  | 7 pins:
 |  |  | 7*6=42 LEDs
 |  | 3RGB*10+12WTE

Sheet: pinout_328p
 | pin
 | 1
 | 2
32-TQFP | 3 | GND
 | 4 | VCC
 | 5 | GND
 | 6 | VCC
 | 7 | crystal
 | 8 | crystal
 | 9
 | 10
 | 11
 | 12
 | 13
 | 14
 | 15
 | 16
 | 17
 | 18
 | 19
 | 20
 | 21
 | 22
 | 23
 | 24
 | 25
 | 26
 | 27
 | 28
 | 29
 | 30
 | 31
 | 32

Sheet: archive
Female 2*3 | DW254S-22-06-85 |  | 5 | 1 | 0.1511 | 0.7555 | 50 | 1 | 0.1211 | 6.055 |  |  |  | 0 | schedule impact? Non-stock
Male 2*3 | X6521WVS-2x03H-C60D74 |  |  |  |  | 0 |  |  |  | 0 |  |  |  | 0 | schedule impact? Non-stock
Battery Holder |  | https://www.aliexpress.us/item/2255800087009710.html |  |  |  | 0 |  |  |  | 0 | 1 | 3 | 19.19 | 57.57
PCB Price |  | Qty 400
Engineering fee: | $8.00
Via Covering: | $0.00
Surface Finish: | $59.00
Castellated Holes: | $102.70
Film: | $1.50
Board: | $102.20
Confirm Production file: | $0.44
Standard PCBA Price
Setup Fee: | $25.00
Stencil: | $8.09
Panel: | $0.00
Large Size: | $0.00
Components(9 items): | $839.52
Feeders Loading fee: | $11.65
SMT Assembly | $66.28
Confirm Parts Placement: | $0.00
Packaging fee: | $0.49 | PCB 5-6 days | castellated pads (ENIG)
 |  | 3-4 days assembly
 |  | 2-4 days DHL
 | $1,224.87 | 14 days aro
 |  | July 21 dead-ish date
 |  | Back-off mulitple weeks for programmming, assembly with stickers, charging, programming
Low CL crystal |  | https://jlcpcb.com/partdetail/TaitienElec-XXDBBCNAOF_16000000MHZ/C558787 |  |  |  |  | 300 | 1 | 0.0932 | 27.96 | https://www.taitien.com/wp-content/uploads/2015/09/Model-Numbering-Guide_CRYSTAL.pdf

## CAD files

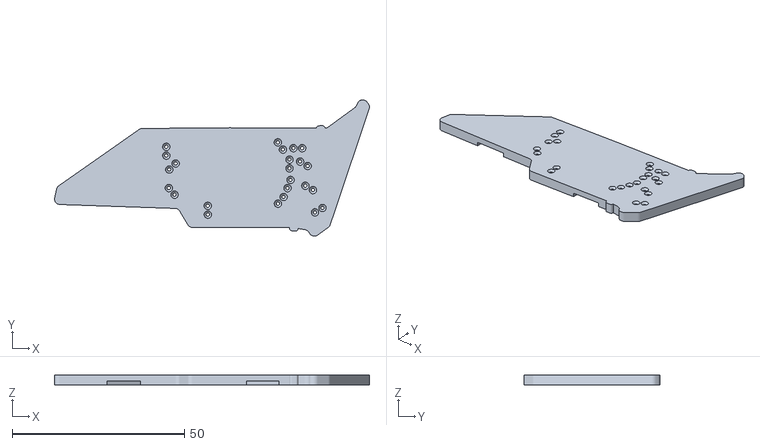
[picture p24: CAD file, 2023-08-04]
cad/assembly_rig_thru_hole_punch_v2-BodyChamfer.stl
91.5 x 39.6 x 3.00

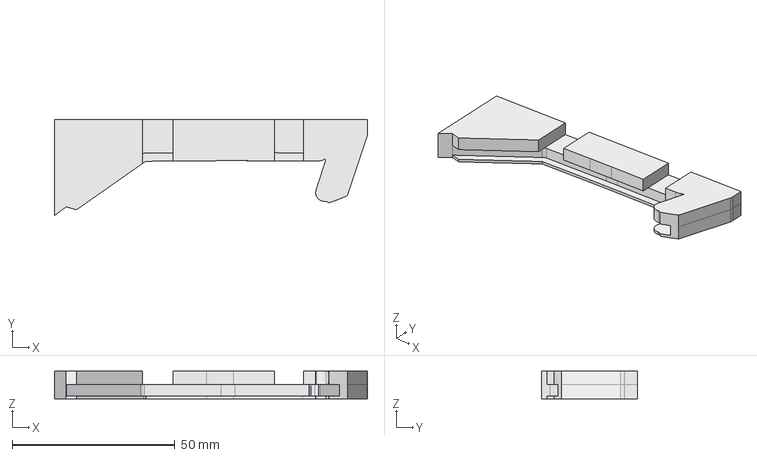
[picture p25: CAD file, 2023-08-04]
cad/assembly_rig_sticker_alignment_v4.FCStd
96.1 x 29.4 x 8.55 mm

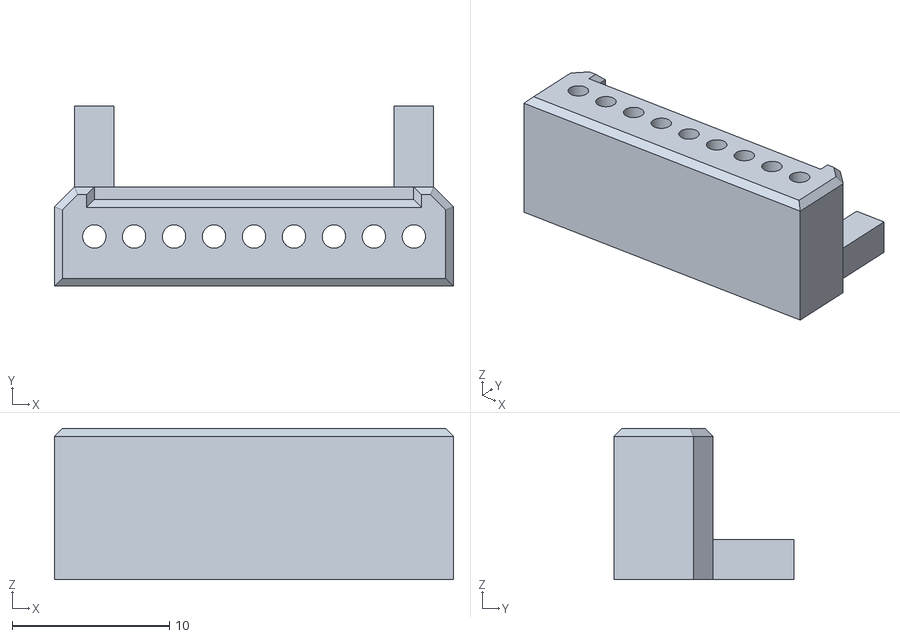
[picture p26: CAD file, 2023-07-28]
cad/assembly_rig_programming_pogo_v3-BodyChamfer.stl
25.4 x 11.5 x 9.60

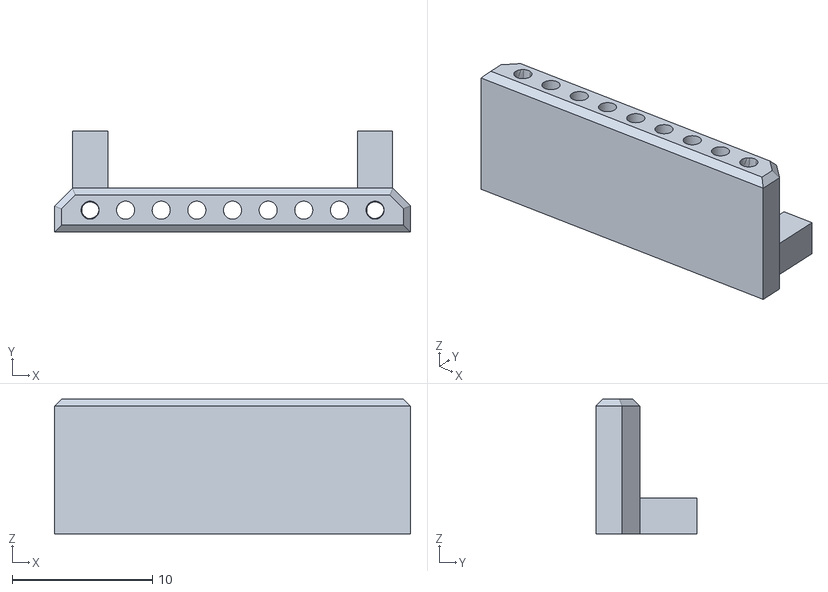
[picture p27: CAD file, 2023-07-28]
cad/assembly_rig_programming_v1-BodyChamfer.stl
25.4 x 7.23 x 9.60

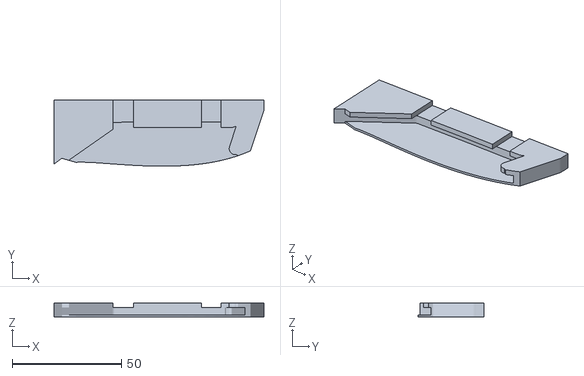
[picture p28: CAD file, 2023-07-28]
cad/assembly_rig_sticker_alignment_v2-BodyPocket005.stl
96.1 x 30.4 x 6.55

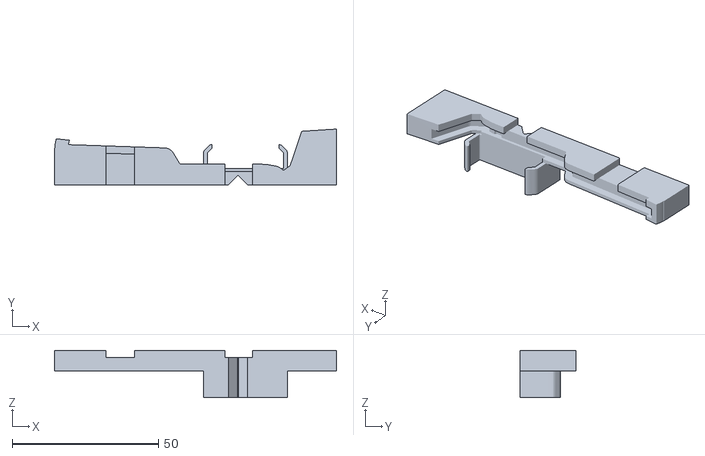
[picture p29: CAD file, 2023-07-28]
cad/assembly_rig_programming_lid_v2-BodyPocket007.stl
96.3 x 19.1 x 16.2

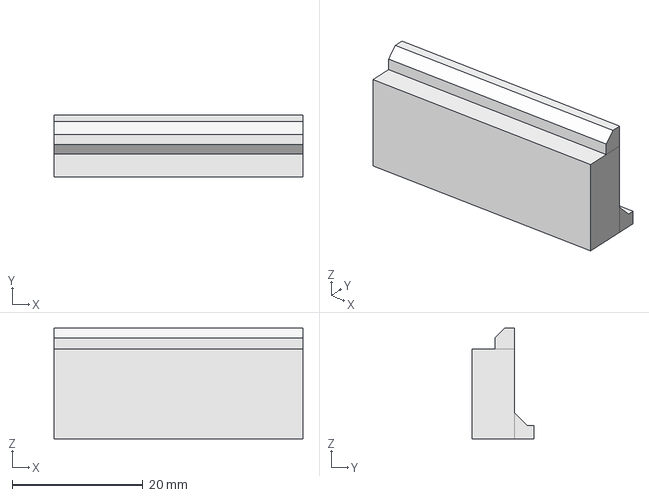
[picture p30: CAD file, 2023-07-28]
cad/assembly_rig_rear_brace_v1.FCStd
38.1 x 9.50 x 16.9 mm

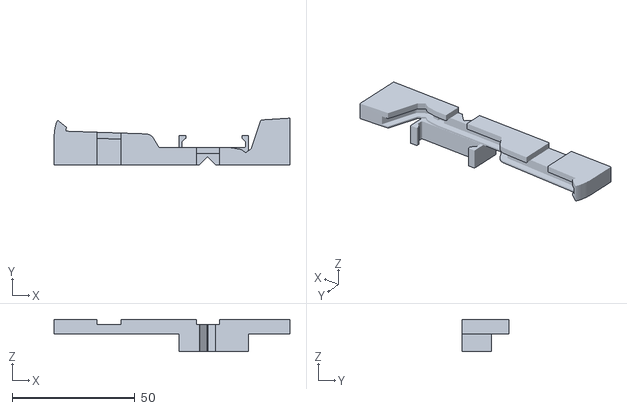
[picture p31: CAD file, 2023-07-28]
cad/assembly_rig_programming_lid_v1-BodyPocket008.stl
96.3 x 19.1 x 13.2

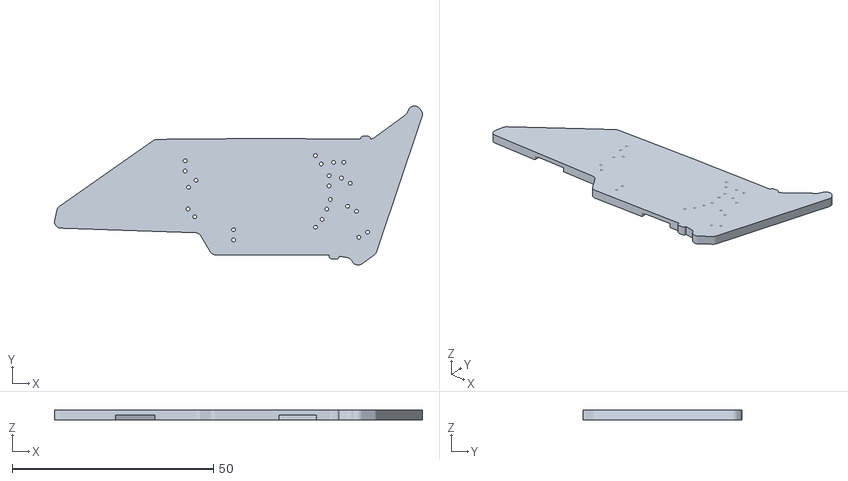
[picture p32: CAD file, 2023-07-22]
cad/assembly_rig_thru_hole_punch_v1-BodyPocket002.stl
91.5 x 39.6 x 2.40

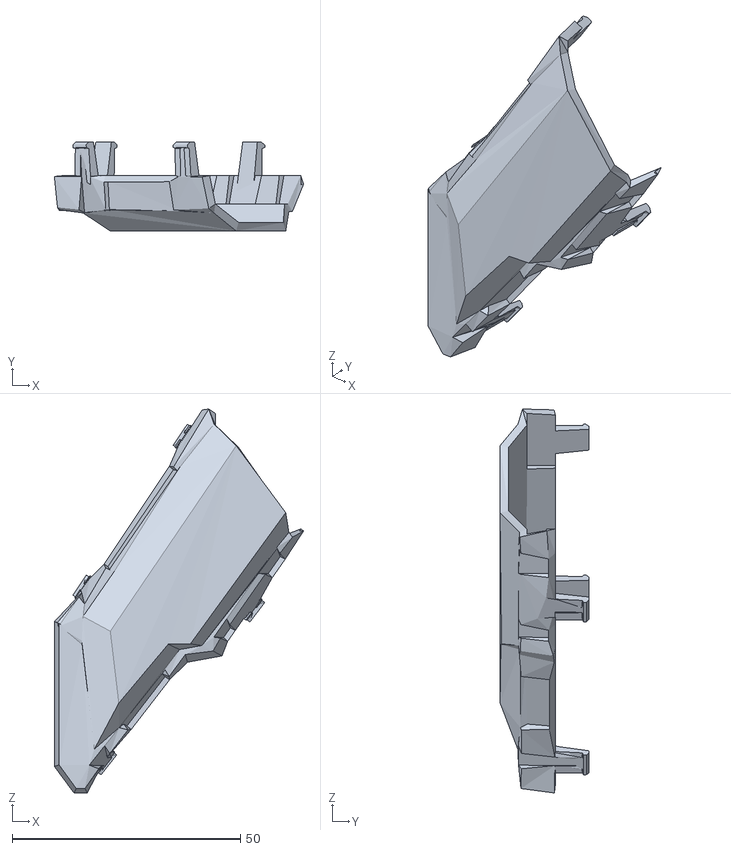
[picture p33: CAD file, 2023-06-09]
doc/ref/files/dc31_badge_top.stl
54.6 x 19.5 x 84.0

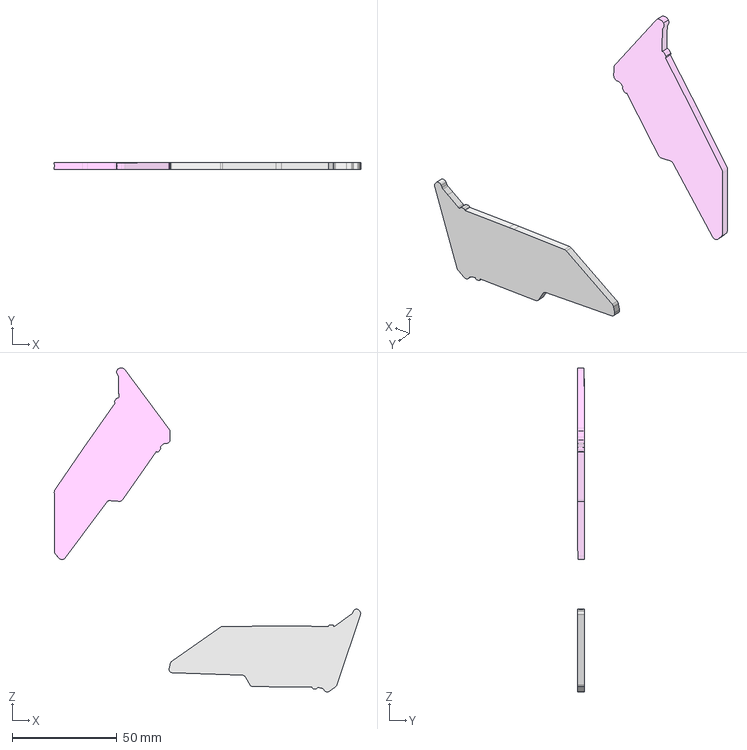
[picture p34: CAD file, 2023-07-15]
doc/ref/stl_assessment_v1.FCStd
146.3 x 3.26 x 154.7 mm

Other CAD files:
cad/assembly_rig_thru_hole_punch_v2.FCStd
cad/assembly_rig_sticker_alignment_v4-BodyPocket006.stl
cad/assembly_rig_programming_lid_v2.FCStd
cad/assembly_rig_rear_brace_v1-BodyChamfer001.stl
cad/assembly_rig_programming_v1.FCStd
cad/assembly_rig_programming_pogo_v3.FCStd
src/api_debug_04/api_debug_04.stp
cad/3d_print_acrylic_pcb_outlines_v1-BodyPocket001.stl
cad/3d_print_acrylic_pcb_outlines_v1.FCStd
cad/3d_print_lipo_402530_v1-BodyPad.stl
cad/3d_print_lipo_402530_v1.FCStd
cad/3d_print_lipo_502540_v1-BodyPad.stl
cad/3d_print_lipo_502540_v1.FCStd
cad/assembly_rig_programming_lid_v1.FCStd
cad/assembly_rig_programming_pogo_v2-BodyChamfer.stl
cad/assembly_rig_programming_pogo_v2.FCStd
cad/assembly_rig_sticker_alignment_v1-BodyPocket005.stl
cad/assembly_rig_sticker_alignment_v1.FCStd
cad/assembly_rig_sticker_alignment_v2.FCStd
cad/assembly_rig_sticker_alignment_v3-BodyPocket006.stl
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

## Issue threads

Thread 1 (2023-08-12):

Rapid power discharge

losttroll, 2023-08-12:
Hi Scott,

I bought one of these from you last night, and I pressed both buttons down it the same time.  It shut off, and even toggling the power button back and forth didn't bring it back. I put in a new battery, and it started flashing normally and then slowly faded (30 seconds) to off, and won't turn back on.

Have you see this before?

scottalmond, 2023-08-14:
- I'm sorry to hear about that issue; that sounds like two different topics realized simultaneously.
- Both buttons being down should have no lasting electrical impact.  It confuses the software state machine but that is cleared with a power cycle.
- I'm unclear which model of unit you have.  If this is the pony unit, they only have a few hours battery life (it was a design trade-off between brightness+re-chargability vs lifespan) so I suspect the battery has just been depleted (and the CR2032 I presume you replaced it with can't take the current draw demand of the LEDs, so the voltage is dropping quickly to the point the LEDs appear dim).  Please remove the dime cell you placed in and then re-install the original LIR2032 dime cell (which uses a different, rechargeable, chemistry).  Then turn the switch to OFF.  I'd recommend charging the unit by applying 5V on the power input pin and GND on the other pin and waiting several hours for the green (cyan) status charging status LED to turn OFF (blue).  Then you should be able to switch ON the unit and operate it normally.
- Sorry I didn't see this message until now.  Depending on your use case, I'd suggest removing the battery entirely and supplying external power (ex. 3.3V) on the battery pin from an external source (when the unit is switched ON).  That should enable you to achieve the necessary current of ~25 mA to power the unit.

losttroll, 2023-08-14:
I have it charging now, the blue and green LEDs are lit.  I'll let you know what happens! Thanks!

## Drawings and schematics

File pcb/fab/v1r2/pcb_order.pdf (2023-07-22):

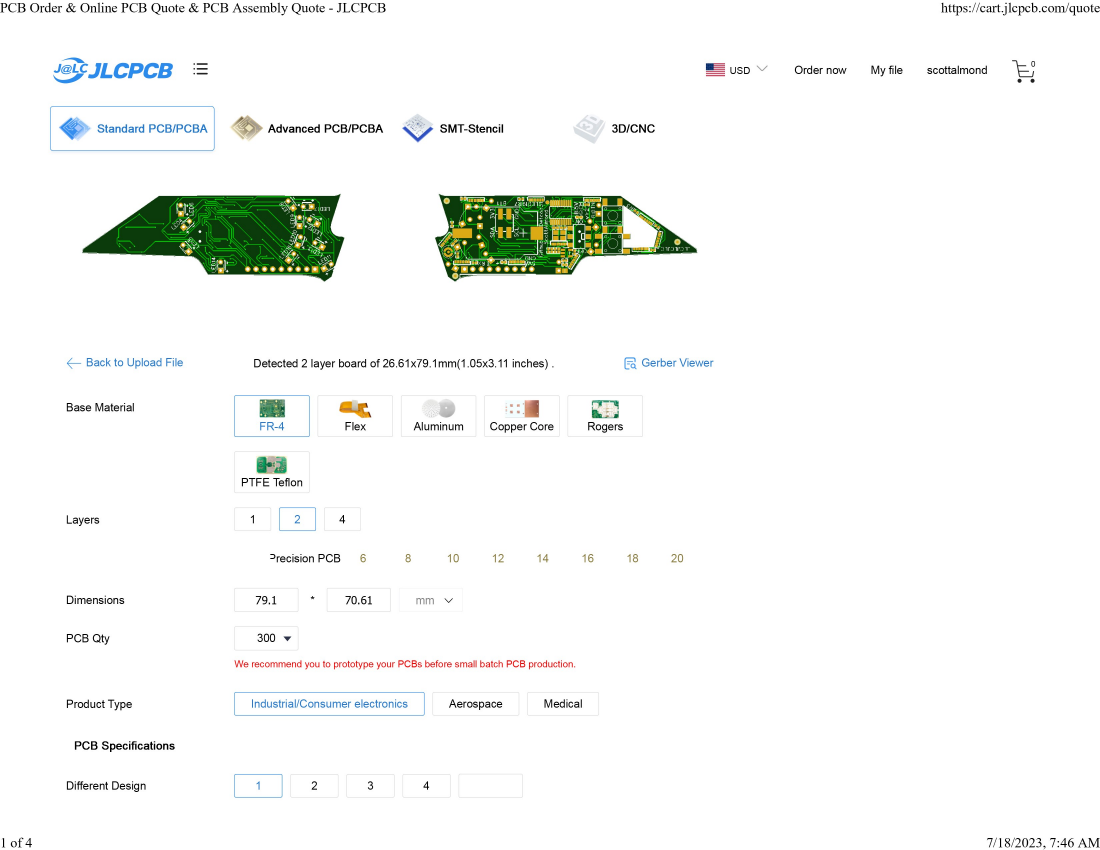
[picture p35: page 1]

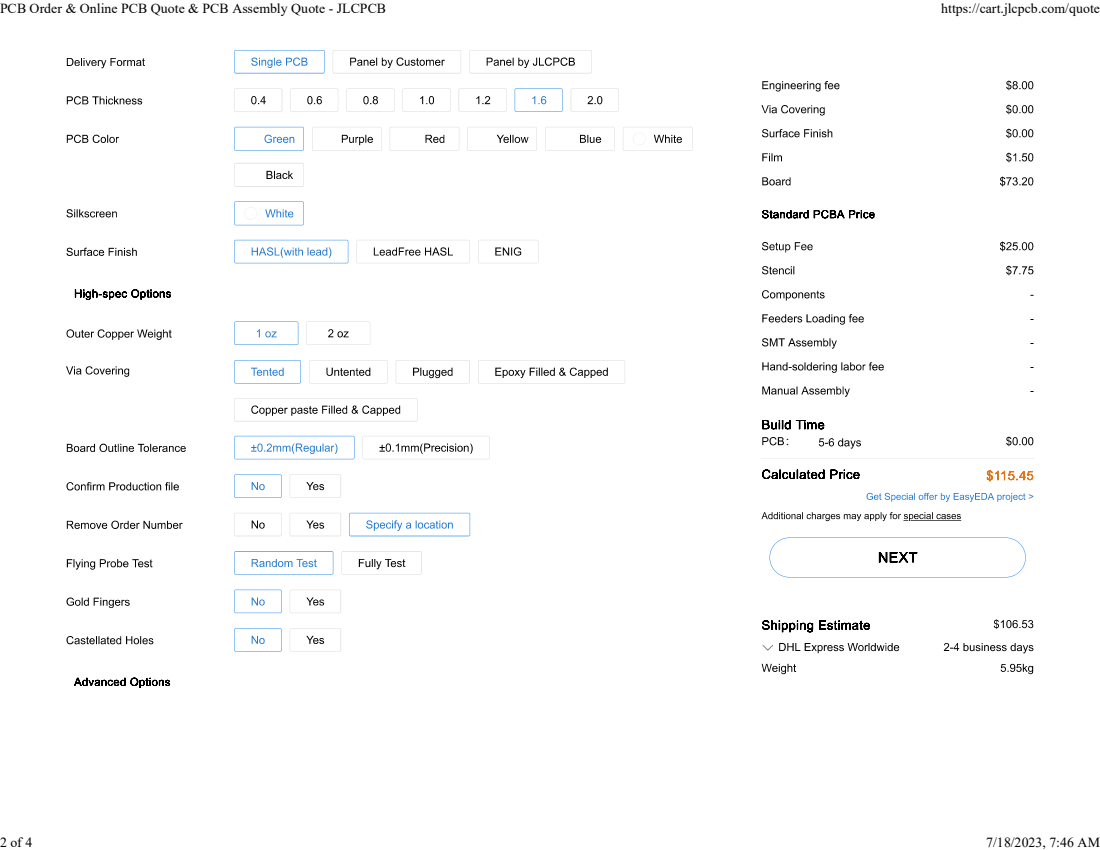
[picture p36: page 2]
PCB Order & Online PCB Quote & PCB Assembly Quote - JLCPCB; https://cart.jlcpcb.com/quote

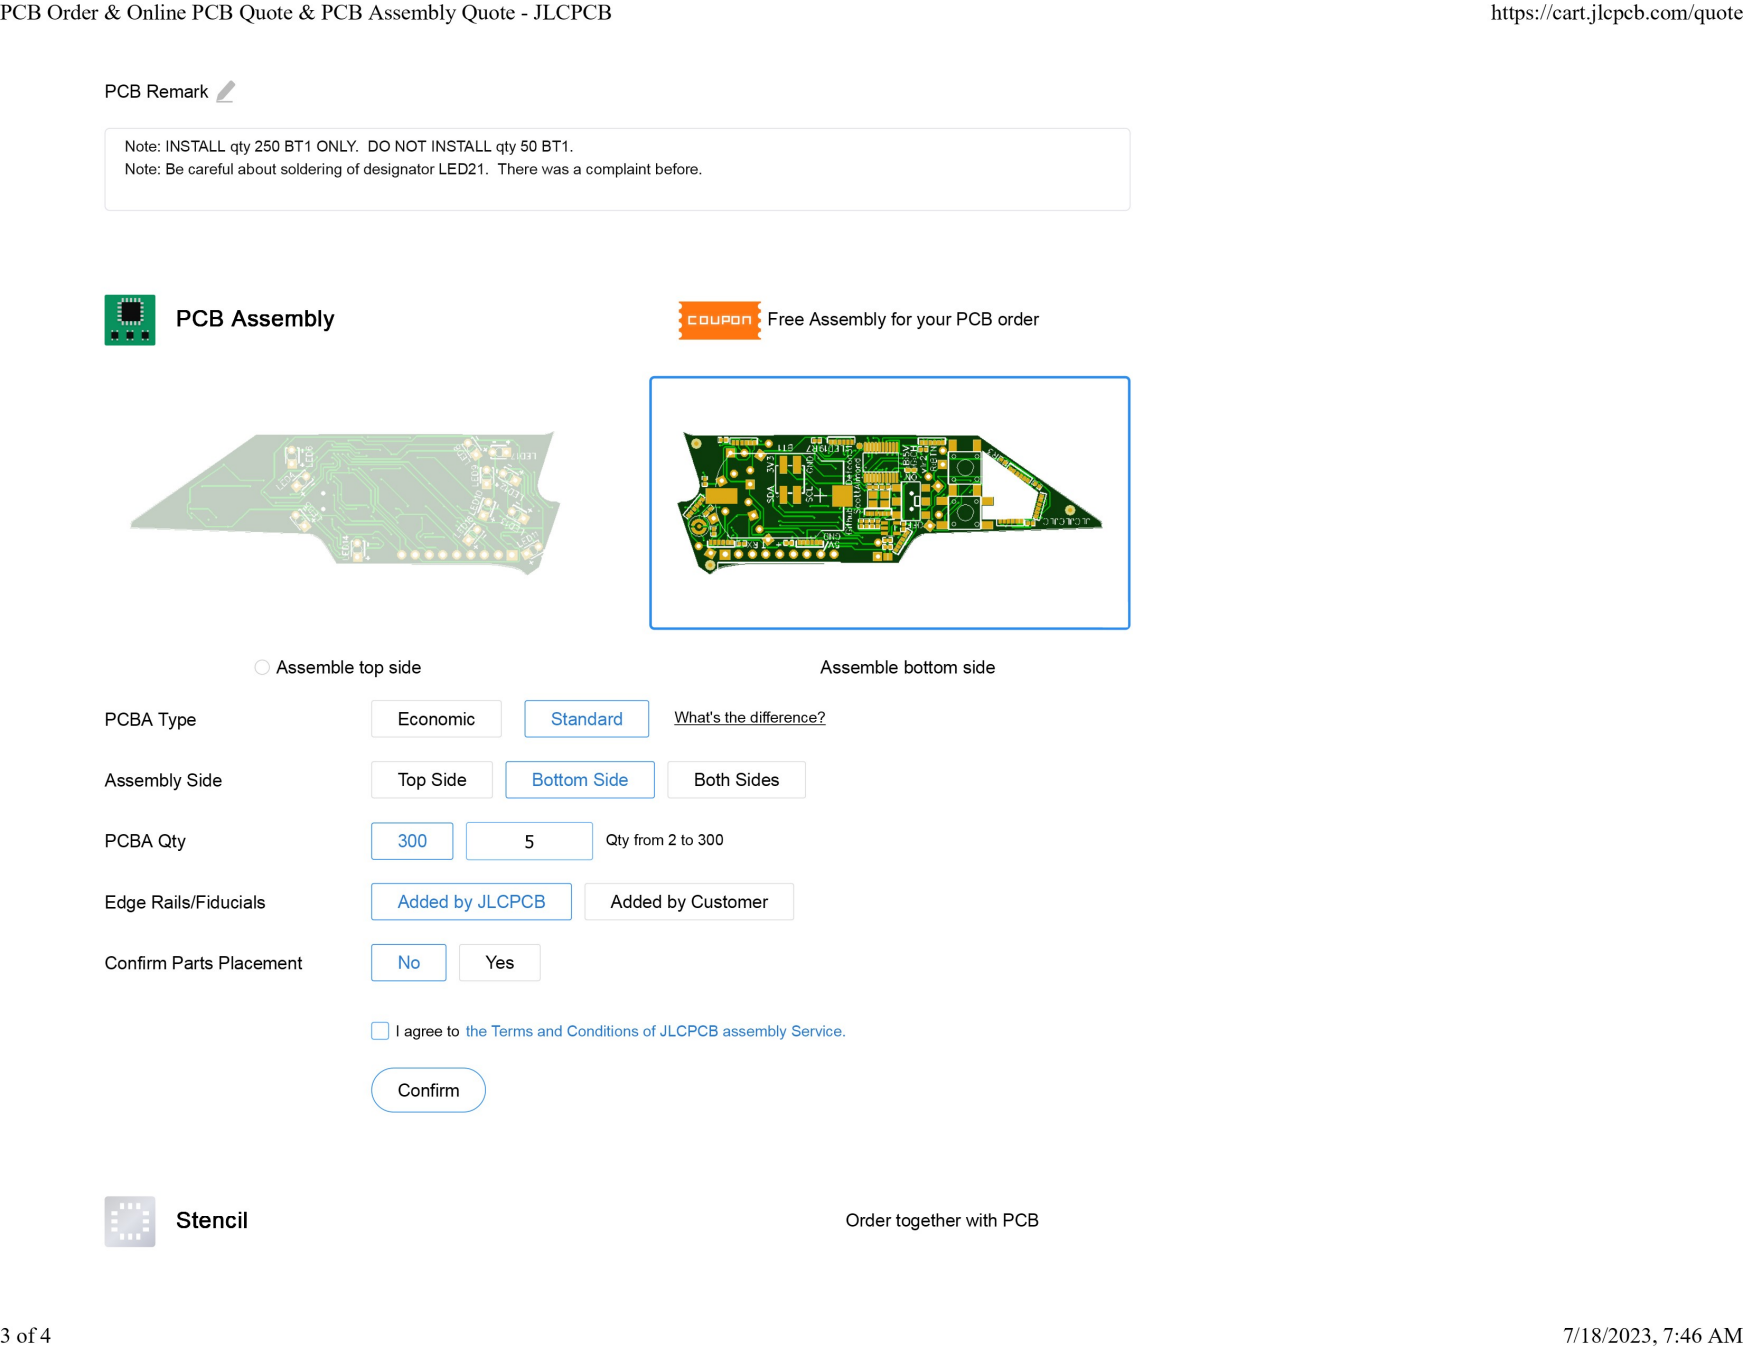
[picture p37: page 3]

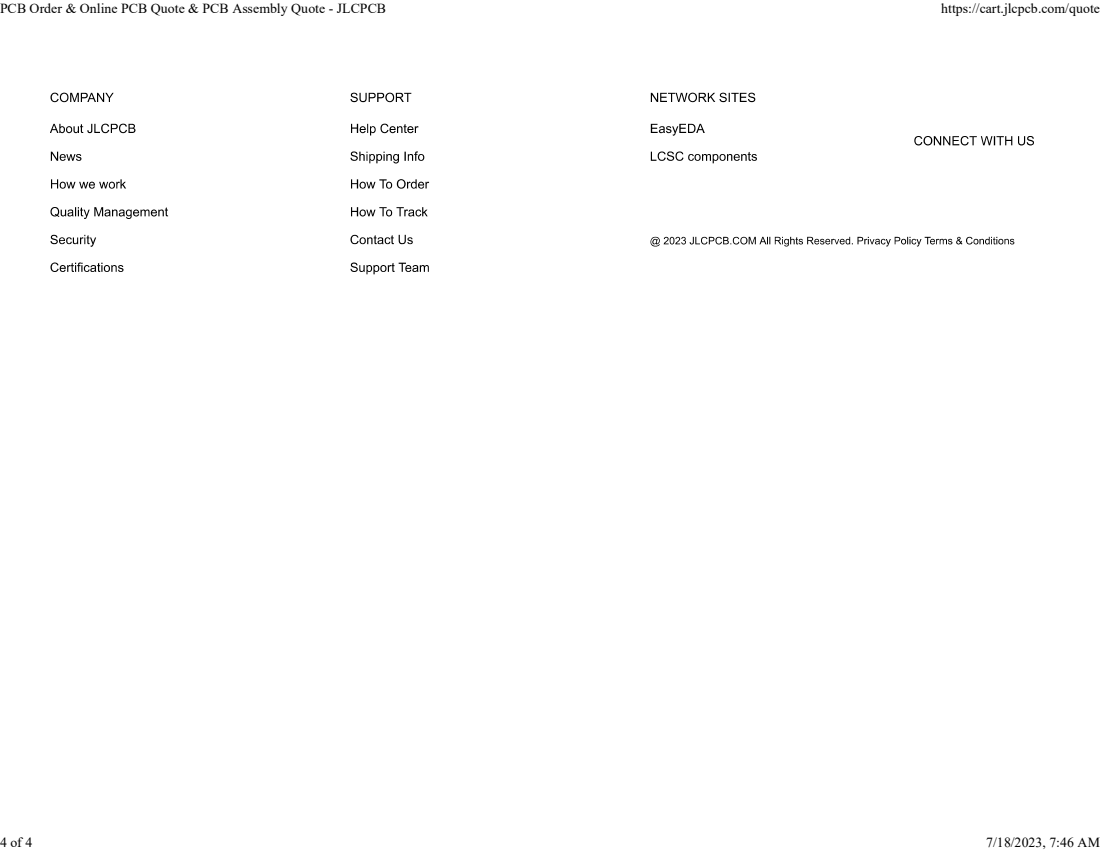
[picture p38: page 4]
PCB Order & Online PCB Quote & PCB Assembly Quote - JLCPCB; https://cart.jlcpcb.com/quote

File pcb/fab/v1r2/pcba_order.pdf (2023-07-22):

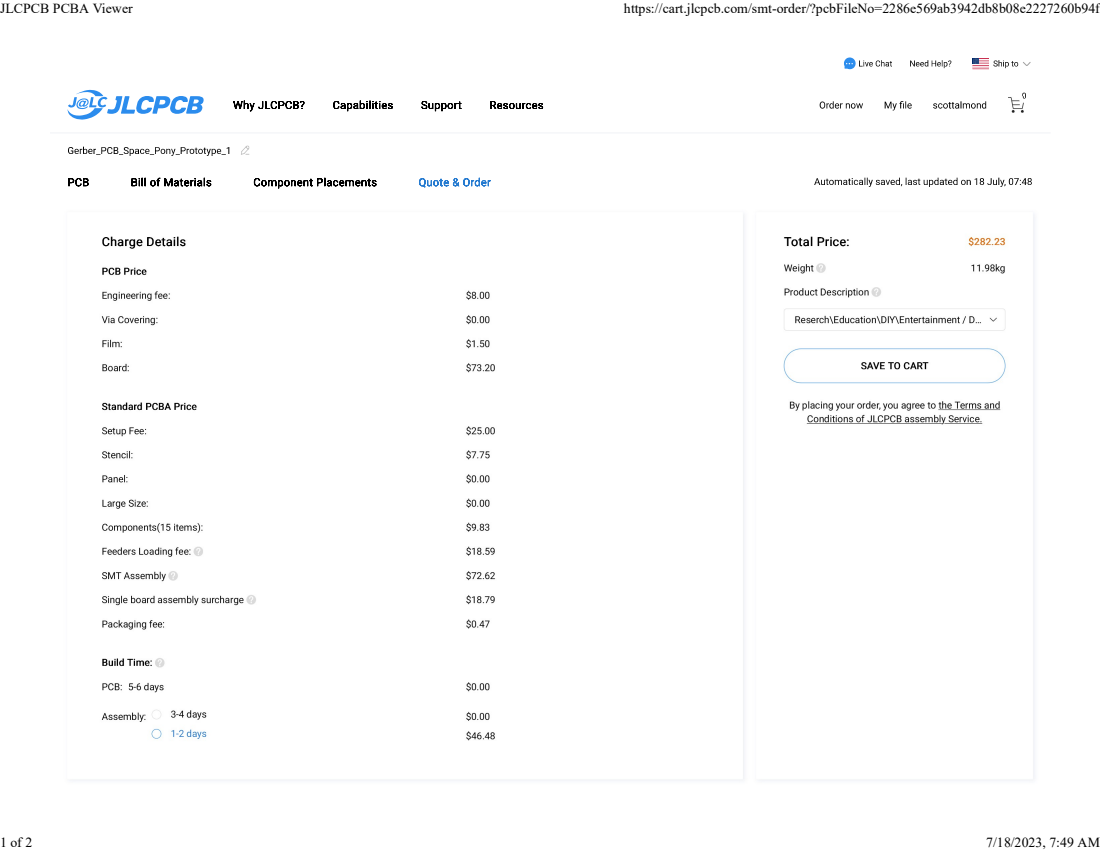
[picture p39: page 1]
JLCPCB PCBA Viewer; https://cart.jlcpcb.com/smt-order/?pcbFileNo=2286e569ab3942db8b08e2227260b94f

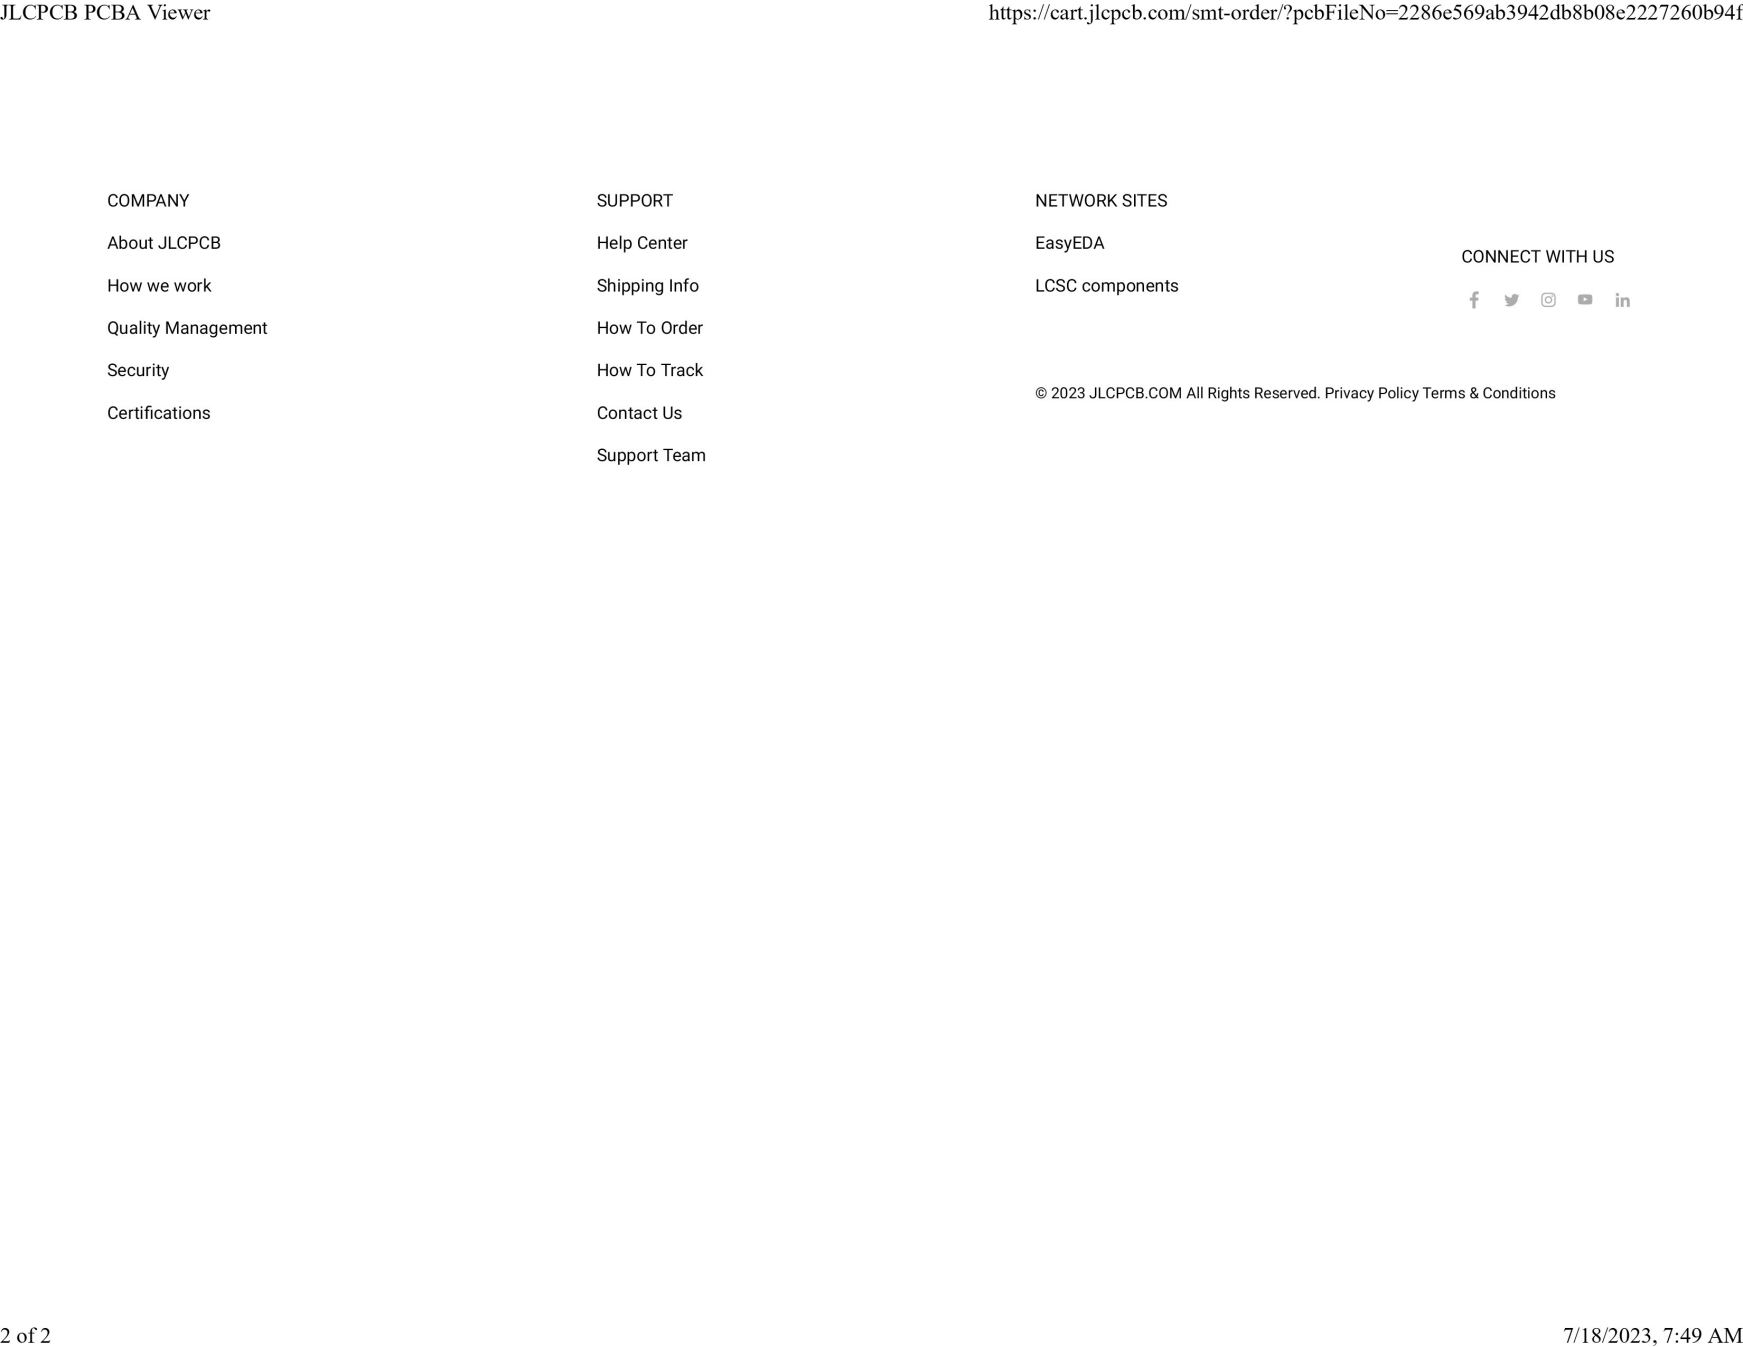
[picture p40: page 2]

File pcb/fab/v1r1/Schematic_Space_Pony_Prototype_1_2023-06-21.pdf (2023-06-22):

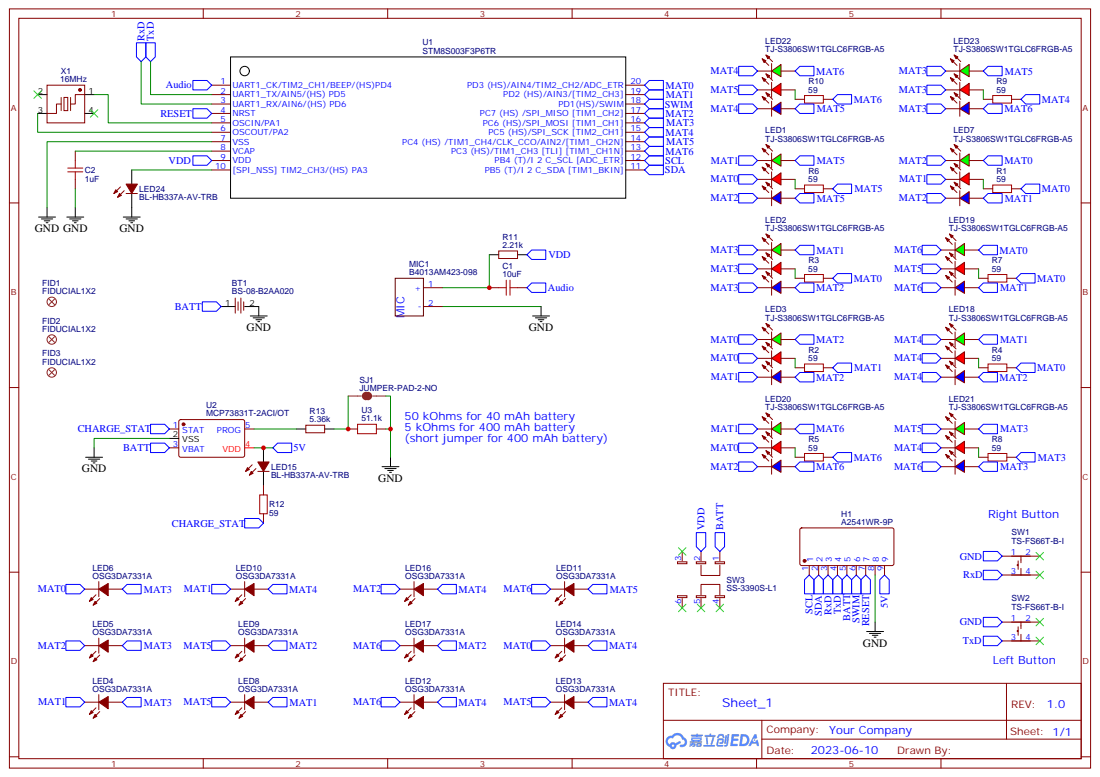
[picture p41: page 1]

5 kOhms for 400 mAh battery
(short jumper for 400 mAh battery)

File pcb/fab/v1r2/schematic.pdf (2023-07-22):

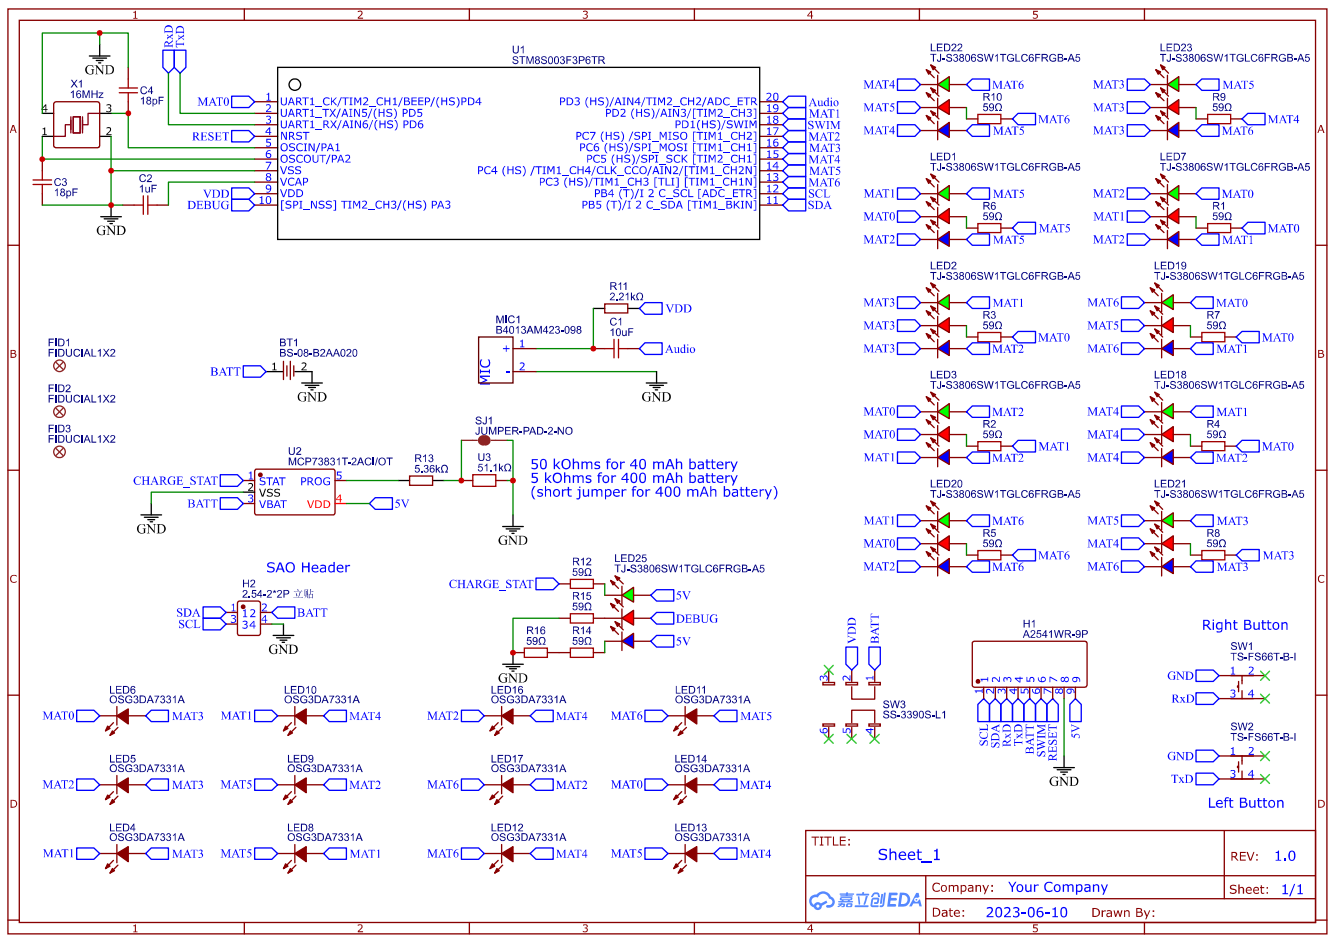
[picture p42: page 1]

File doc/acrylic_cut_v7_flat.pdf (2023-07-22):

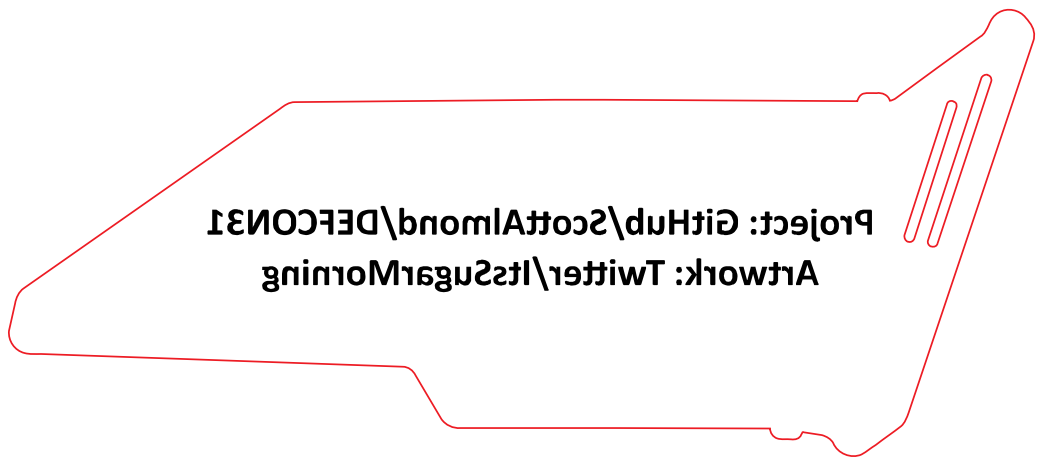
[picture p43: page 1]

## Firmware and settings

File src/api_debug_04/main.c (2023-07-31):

/* MAIN.C file
 * 
 * Copyright (c) 2002-2005 STMicroelectronics
 */
#include "STM8s.h"
#include "stm8s103_ADC.h"

#define LED_COUNT 43 //10 RGB (3 LEDs each) + 12 white + 1 debug
unsigned long tms=0,tms2=0,tms3=0;

//application space settings
u8 pwm_brightness_buffer[LED_COUNT];

//LED pwm control state machine
u8 pwm_brightness[LED_COUNT][2][2];//array index, [led index, led pwm], [A vs B side live]
u16 pwm_sleep[2];//[A vs B side live], how many LED LSBs to wait with LEDs OFF before putting LEDs back ON
u8 pwm_led_count[2];//how many LEDs to cycle through
u16 pwm_sleep_remaining=0;
u8 pwm_led_index=0;
u8 pwm_state=0;//LSB (bit 0) is index of pwm_brightness to pull pwm info from.  bit 1 is a flag the application layer raises for the API layer to clear requesting a switch

void setMatrixHighZ(void);
void setLED(bool is_rgb,int led_index,int rgb_index);
void setRGB(int led_index,int rgb_index);
void setWhite(int led_index);
void Serial_print_int(int number);
void Serial_newline(void);
void Serial_print_string(char string[]);
//int ADC_Read(ADC_CHANNEL_TypeDef ADC_Channel_Number);

//const bool is_rev_1=true;//mat0 placement


int main()
{
	/*
	//GPIO_Init(GPIOA, GPIO_PIN_3, GPIO_MODE_OUT_PP_HIGH_FAST);
	GPIO_Init(GPIOD, GPIO_PIN_5, GPIO_MODE_OUT_PP_HIGH_FAST);
	//GPIO_Init(GPIOD, GPIO_PIN_3, GPIO_MODE_OUT_PP_HIGH_SLOW);//MAT0
	GPIO_Init(GPIOD, GPIO_PIN_2, GPIO_MODE_OUT_PP_HIGH_SLOW);//MAT1
	GPIO_Init(GPIOC, GPIO_PIN_7, GPIO_MODE_OUT_PP_HIGH_SLOW);//MAT2
	GPIO_WriteHigh(GPIOA, GPIO_PIN_3);
	GPIO_WriteHigh(GPIOD, GPIO_PIN_5);	
	while (1)
	{
		unsigned int iter;//16 bit signed
		GPIO_WriteLow(GPIOD, GPIO_PIN_2);
		GPIO_WriteHigh(GPIOC, GPIO_PIN_7);
		GPIO_WriteHigh(GPIOA, GPIO_PIN_3);
		GPIO_WriteHigh(GPIOD, GPIO_PIN_5);
		for(iter=0;iter<30000;iter++){}
		GPIO_WriteHigh(GPIOD, GPIO_PIN_2);
		GPIO_WriteLow(GPIOC, GPIO_PIN_7);
		GPIO_WriteLow(GPIOA, GPIO_PIN_3);
		GPIO_WriteLow(GPIOD, GPIO_PIN_5);
		for(iter=0;iter<30000;iter++){}
	}*/
	const int test_mode=9;
	const uint8_t rms_lookup[16]={9,18,28,38,48,58,69,80,92,105,118,134,151,173,200,241};
	uint8_t reading,mean,mean_diff;
	unsigned long old_mean=0,mean_sum=0,mean_low=0,mean_high=0;
	unsigned sound_level=0;
	uint8_t mean_threshold=16;
	uint8_t mean_threshold_8=1;
	uint16_t mean_threshold_16=0x0100;
	unsigned int rms=0;
	const long adc_captures=1<<8;
	unsigned long iter,rep;
	int debug=0;
	unsigned int my_min,my_max;
	for(rep=0;rep<1;rep++)
		for(iter=0;iter<10000;iter++){}
  //CLK_PeripheralClockConfig(CLK_PERIPHERAL_UART1, ENABLE); 
	
	if(test_mode!=4 && test_mode!=5 && test_mode!=9)
	{
		GPIO_Init(GPIOD, GPIO_PIN_5, GPIO_MODE_OUT_PP_HIGH_FAST);
		GPIO_Init(GPIOD, GPIO_PIN_6, GPIO_MODE_IN_PU_NO_IT);
		UART1_DeInit();
		UART1_Init(115200, UART1_WORDLENGTH_8D, UART1_STOPBITS_1, UART1_PARITY_NO, UART1_SYNCMODE_CLOCK_DISABLE, UART1_MODE_TXRX_ENABLE);
		//UART1_Init(1000000, UART1_WORDLENGTH_8D, UART1_STOPBITS_1, UART1_PARITY_NO, UART1_SYNCMODE_CLOCK_DISABLE, UART1_MODE_TXRX_ENABLE);
		UART1_Cmd(ENABLE);
	}
	
	switch(test_mode)
	{
		case 0:
		{
			//GPIO_Init(GPIOD, GPIO_PIN_5, GPIO_MODE_OUT_PP_LOW_SLOW);//TxD
			while(1)
			{
				unsigned int led_index,rgb_index;
				for(rgb_index=0;rgb_index<3;rgb_index++)
				{
					for(led_index=0;led_index<10;led_index++)
					{
						setMatrixHighZ();
						setRGB(led_index,rgb_index);
						for(iter=0;iter<30000;iter++){}
						debug++;
						/*if(debug%2)
							GPIO_WriteHigh(GPIOD,GPIO_PIN_5);
						else
							GPIO_WriteLow(GPIOD,GPIO_PIN_5);*/
						//if((debug%10)==0)
						//{
							Serial_print_string("counter: ");
							Serial_print_int(debug);
							//UART1_SendData8('0'+((debug/10)%10));
							//UART1_SendData8('\n');
							Serial_newline();
						//}
					}
				}
				for(led_index=0;led_index<12;led_index++)
				{
					setMatrixHighZ();
					setWhite(led_index);
					for(iter=0;iter<30000;iter++){}
				}
			}
		}
		case 1:
		{
		  while(1)
			{
				rep=ADC_Read(AIN4);
				my_min=rep;
				my_max=rep;
				for(iter=0;iter<1000;iter++)
				{
					rep=ADC_Read(AIN4);
					my_min=my_min<rep?my_min:rep;
					my_max=my_max>rep?my_max:rep;
				}
				Serial_print_string("adc: ");
				Serial_print_int(rep);
				Serial_print_string(", ");
				Serial_print_int(my_max-my_min);
				Serial_newline();
				for(iter=0;iter<10000;iter++){}
			}
		}
		case 2:
		{	 
			ADC1_DeInit();
			ADC1_Init(ADC1_CONVERSIONMODE_CONTINUOUS, 
							 AIN4,
							 ADC1_PRESSEL_FCPU_D2,//D18 
							 ADC1_EXTTRIG_TIM, 
							 DISABLE, 
							 ADC1_ALIGN_RIGHT, //left to put 8 bits in ADC1->DRH; right for all 10 bits with ADC1_GetConversionValue()
							 ADC1_SCHMITTTRIG_ALL, 
							 DISABLE);
			ADC1_Cmd(ENABLE);
		  while(1)
			{
				/*ADC1_StartConversion();
				while(ADC1_GetFlagStatus(ADC1_FLAG_EOC) == FALSE);
				rep = ADC1_GetConversionValue();
				ADC1_ClearFlag(ADC1_FLAG_EOC);
				//rep=ADC_Read(AIN4);
				my_min=rep;
				my_max=rep;*/
				/*if(debug%20==0)
				{
					ADC1_DeInit();
					GPIO_Init(GPIOD, GPIO_PIN_3, GPIO_MODE_OUT_PP_LOW_FAST);
					ADC1_Init(ADC1_CONVERSIONMODE_CONTINUOUS, 
									 AIN4,
									 ADC1_PRESSEL_FCPU_D2, 
									 ADC1_EXTTRIG_TIM, 
									 DISABLE, 
									 ADC1_ALIGN_RIGHT, 
									 ADC1_SCHMITTTRIG_ALL, 
									 DISABLE);
					ADC1_Cmd(ENABLE);
				}*/
				rms=0;
				//old_mean=mean;
				mean_sum=0;
				mean_low=mean+mean_threshold;
				mean_high=mean-mean_threshold;
				for(iter=0;iter<adc_captures;iter++)
				{
					//rep=ADC_Read(AIN4);
					ADC1_StartConversion();
					while(ADC1_GetFlagStatus(ADC1_FLAG_EOC) == FALSE);
					//rep=ADC1_GetConversionValue();
					reading=ADC1->DRL;
					mean_sum += reading;
					rms+=reading>mean_low || reading<mean_high;
					//mean_diff=reading>mean?(reading-mean):(mean-reading);
					//rms+=mean_diff>mean_threshold?1:0;
					//rms+=(reading-mean)*(reading-mean);
					ADC1_ClearFlag(ADC1_FLAG_EOC);
					//my_min=my_min<rep?my_min:rep;
					//my_max=my_max>rep?my_max:rep;
				}
				if(rms>9) mean_threshold++;
				if(rms==0) mean_threshold--;
				mean=(mean_sum)/(adc_captures);
				if(sound_level/32<mean_threshold) sound_level++;
				if(sound_level/32>mean_threshold) sound_level--;
				if(debug%4==0)
				{
					Serial_print_string("adc: ");
					Serial_print_int(mean);
					Serial_print_string(", ");
					if(rms<9) Serial_print_string("0");
					if(rms==0) Serial_print_string("0");
					Serial_print_int(rms);
					Serial_print_string(", ");
					if(mean_threshold<9) Serial_print_string("0");
					Serial_print_int(mean_threshold);
					Serial_print_string(", ");
					if(sound_level/8<9) Serial_print_string("0");
					Serial_print_int(sound_level/8);
					if(debug%10==0) Serial_print_string("*");
					Serial_newline();
				}
				if(mean_threshold>10)
				{//green on led 22 and 23
					//6-4, 5-3
					//
					GPIO_Init(GPIOC, GPIO_PIN_3,GPIO_MODE_OUT_PP_HIGH_SLOW);
					GPIO_Init(GPIOC, GPIO_PIN_5,GPIO_MODE_OUT_PP_LOW_SLOW);
				}else{
					GPIO_Init(GPIOC, GPIO_PIN_4,GPIO_MODE_OUT_PP_HIGH_SLOW);
					GPIO_Init(GPIOC, GPIO_PIN_6,GPIO_MODE_OUT_PP_LOW_SLOW);
				}
			for(iter=0;iter<10;iter++){}
				GPIO_Init(GPIOC, GPIO_PIN_7 | GPIO_PIN_6 | GPIO_PIN_5 | GPIO_PIN_4 | GPIO_PIN_3, GPIO_MODE_IN_FL_NO_IT);//2, 3, 4, 5, 6
				GPIO_Init(GPIOD, GPIO_PIN_2, GPIO_MODE_IN_FL_NO_IT);//0, 1
							
				debug++;
				//for(iter=0;iter<10000;iter++){}
			}
		}
		case 3:
		{
			ADC1_DeInit();
			ADC1_Init(ADC1_CONVERSIONMODE_CONTINUOUS, 
							 AIN4,
							 ADC1_PRESSEL_FCPU_D2,//D18 
							 ADC1_EXTTRIG_TIM, 
							 DISABLE, 
							 ADC1_ALIGN_RIGHT, //left to put 8 bits in ADC1->DRH; right for all 10 bits with ADC1_GetConversionValue()
							 ADC1_SCHMITTTRIG_ALL, 
							 DISABLE);
			ADC1_Cmd(ENABLE);
			while(1)
			{
				debug++;
				rms=0;//8 bit
				//old_mean=mean;
				mean_sum=0;//16 bit
				//mean_low=mean+mean_threshold;
				//mean_high=mean-mean_threshold;
				iter=0;
				do{
					//rep=ADC_Read(AIN4);
					ADC1_StartConversion();
					while(ADC1_GetFlagStatus(ADC1_FLAG_EOC) == FALSE);
					//rep=ADC1_GetConversionValue();
					reading=ADC1->DRL;
					mean_sum += reading;
					//rms+=reading>mean_low || reading<mean_high;
					mean_diff=reading>mean?(reading-mean):(mean-reading);
					rms+=mean_diff>mean_threshold_8;
					//rms+=(reading-mean)*(reading-mean);
					ADC1_ClearFlag(ADC1_FLAG_EOC);
					//my_min=my_min<rep?my_min:rep;
					//my_max=my_max>rep?my_max:rep;
					iter++;
					iter%=256;//8 bit unsigned
				}while(iter!=0);//run 255 times
				mean=((uint16_t)mean+mean_sum/256)/2;
				mean_threshold_16=(mean_threshold_16+(((uint16_t)rms_lookup[rms/16])*mean_threshold_16)/32)/2;
				mean_threshold_8=mean_threshold_16/256;
				if(mean_threshold_8==0)
				{//correct unflow; state machine cannot scale 0 properly
					mean_threshold_8=1;
					mean_threshold_16=0x0100;
				}
				if(debug%1==0)
				{
					//Serial_print_string("mean: ");
					if(mean==0) Serial_print_string("0");
					Serial_print_int(mean);
					//Serial_print_string(", rms: ");
					Serial_print_string(" ");
					//if(rms<99) Serial_print_string("0");
					//if(rms<9) Serial_print_string("0");
					if(rms==0) Serial_print_string("0");
					Serial_print_int(rms);
					//Serial_print_string(", threshold: ");
					Serial_print_string(" ");
					if(mean_threshold_8==0) Serial_print_string("0");
					Serial_print_int(mean_threshold_8);
					//if(debug%100==0) Serial_print_string("*");
					Serial_newline();
				}
			}
		}
		case 4:
		{//button test
			GPIO_Init(GPIOD, GPIO_PIN_5,GPIO_MODE_IN_PU_NO_IT);
			GPIO_Init(GPIOD, GPIO_PIN_6,GPIO_MODE_IN_PU_NO_IT);
			while(1)
			{
			  setMatrixHighZ();
				if(!GPIO_ReadInputPin(GPIOD, GPIO_PIN_5))
				{//green on led 22 and 23
					//6-4, 5-3
					//
					GPIO_Init(GPIOC, GPIO_PIN_3,GPIO_MODE_OUT_PP_HIGH_SLOW);
					GPIO_Init(GPIOC, GPIO_PIN_5,GPIO_MODE_OUT_PP_LOW_SLOW);
				}else if(!GPIO_ReadInputPin(GPIOD, GPIO_PIN_6)){
					GPIO_Init(GPIOC, GPIO_PIN_4,GPIO_MODE_OUT_PP_HIGH_SLOW);
					GPIO_Init(GPIOC, GPIO_PIN_6,GPIO_MODE_OUT_PP_LOW_SLOW);
				}
			}
		}
		case 5:
		{//interrupts 1 ms counter
			CLK->CKDIVR &= (u8)~(CLK_CKDIVR_HSIDIV);			// fhsi= fhsirc (HSIDIV= 0)
			
			GPIO_Init(GPIOD, GPIO_PIN_5, GPIO_MODE_OUT_PP_HIGH_FAST);
			GPIO_Init(GPIOD, GPIO_PIN_6, GPIO_MODE_IN_PU_NO_IT);
			UART1_DeInit();
			UART1_Init(1000000, UART1_WORDLENGTH_8D, UART1_STOPBITS_1, UART1_PARITY_NO, UART1_SYNCMODE_CLOCK_DISABLE, UART1_MODE_TXRX_ENABLE);
			//UART1_Init(1000000, UART1_WORDLENGTH_8D, UART1_STOPBITS_1, UART1_PARITY_NO, UART1_SYNCMODE_CLOCK_DISABLE, UART1_MODE_TXRX_ENABLE);
			UART1_Cmd(ENABLE);
			
			Serial_print_string("Mode: ");
			Serial_print_int(test_mode);
			Serial_newline();
			
			
			Serial_print_string("Params v2: ");
			//Mask:
			/*Serial_print_int(CLK_CKDIVR_CPUDIV);//7 0b000_0111
			Serial_print_string(" ");
			Serial_print_int(CLK_CKDIVR_HSIDIV);//24 0b0001_1000
			Serial_print_string(" ");
			Serial_print_int(CLK_CCOR_CCOSEL);//30 0b0001_1110*/
			Serial_print_int(CLK->CKDIVR);//24 0001_1000
			Serial_print_string(" ");
			Serial_print_int(CLK->CCOR);//0
			Serial_newline();
			
			TIM4->PSCR= 7;// init divider register /128	
			TIM4->ARR= 256 - (u8)(-125);// init auto reload register
			TIM4->EGR= TIM4_EGR_UG;// update registers
			TIM4->CR1|= TIM4_CR1_ARPE | TIM4_CR1_URS |TIM4_CR1_CEN;// enable timer
			TIM4->IER= TIM4_IER_UIE;// enable TIM4 interrupt
			enableInterrupts();
			while(1)
			{
				if(tms%1000==0 && mean_sum!=tms/1000)
				{
					Serial_print_string("time: ");
					mean_sum=tms/1000;
					Serial_print_int(tms/1000);
					Serial_newline();
					/*if(tms/1000%2)
					{
						GPIO_Init(GPIOA, GPIO_PIN_3,GPIO_MODE_OUT_PP_HIGH_SLOW);
					}else{
						GPIO_Init(GPIOA, GPIO_PIN_3,GPIO_MODE_OUT_PP_LOW_SLOW);
					}*/
				}
				setMatrixHighZ();
				mean_low=tms%20;
				mean_high=(tms/20)%100;
				if(mean_low>(mean_high/4) ^ (tms/2000)%2)
				{
					setRGB(4,1);
				}else{
					//setRGB(5,1);
					setRGB(4,0);
				}
			}
		}
		case 6:
		{//interrupts 1 ms counter
			Serial_print_string("Mode: ");
			Serial_print_int(test_mode);
			Serial_newline();
			
			
			//https://blog.mark-stevens.co.uk/2012/07/configuring-the-stm8s-system-clock-the-way-of-the-register/
			Serial_print_string("Params: ");
			Serial_print_int(CLK->CKDIVR);//
			Serial_print_string(" ");
			Serial_print_int(CLK->CCOR);//
			Serial_newline();
			
			TIM4->PSCR= 7;// init divider register /128	
			TIM4->ARR= 256 - (u8)(-128);// init auto reload register
			TIM4->EGR= TIM4_EGR_UG;// update registers
			TIM4->CR1|= TIM4_CR1_ARPE | TIM4_CR1_URS |TIM4_CR1_CEN;// enable timer
			TIM4->IER= TIM4_IER_UIE;// enable TIM4 interrupt
			enableInterrupts();
			while(1)
			{
				for(iter=0;iter<5000;iter++){}
				Serial_print_string("time: ");
				Serial_print_int(tms>>16);
				Serial_print_string(" ");
				Serial_print_int((uint16_t)tms);
				Serial_newline();
			}
		}
		case 7:
		{//steeple chase pattern, RGB
			CLK->CKDIVR &= (u8)~(CLK_CKDIVR_HSIDIV);			// fhsi= fhsirc (HSIDIV= 0)
			
			GPIO_Init(GPIOD, GPIO_PIN_5, GPIO_MODE_OUT_PP_HIGH_FAST);
			GPIO_Init(GPIOD, GPIO_PIN_6, GPIO_MODE_IN_PU_NO_IT);
			UART1_DeInit();
			UART1_Init(1000000, UART1_WORDLENGTH_8D, UART1_STOPBITS_1, UART1_PARITY_NO, UART1_SYNCMODE_CLOCK_DISABLE, UART1_MODE_TXRX_ENABLE);
			//UART1_Init(1000000, UART1_WORDLENGTH_8D, UART1_STOPBITS_1, UART1_PARITY_NO, UART1_SYNCMODE_CLOCK_DISABLE, UART1_MODE_TXRX_ENABLE);
			UART1_Cmd(ENABLE);
			
			Serial_print_string("Mode: ");
			Serial_print_int(test_mode);
			Serial_newline();
			
			TIM4->PSCR= 7;// init divider register /128	
			TIM4->ARR= 256 - (u8)(-125);// init auto reload register
			TIM4->EGR= TIM4_EGR_UG;// update registers
			TIM4->CR1|= TIM4_CR1_ARPE | TIM4_CR1_URS |TIM4_CR1_CEN;// enable timer
			TIM4->IER= TIM4_IER_UIE;// enable TIM4 interrupt
			enableInterrupts();
			
			while(1)
			{
				//if(tms%100==0 && mean_sum!=tms/100)
				{
					setMatrixHighZ();
					mean_sum=tms/60;
					mean_low=tms%2;//is high or low charlieplexing
					mean_high=(mean_sum/2)%5;//which LED, 2x on display lit
					sound_level=(mean_sum/10)%3;//RGB
					setRGB(mean_high+(mean_low?5:0),sound_level);
				}
			}
		}
		case 8:
		{//RGB curretndraw and voltage test
			CLK->CKDIVR &= (u8)~(CLK_CKDIVR_HSIDIV);			// fhsi= fhsirc (HSIDIV= 0)
			
			TIM4->PSCR= 7;// init divider register /128	
			TIM4->ARR= 256 - (u8)(-125);// init auto reload register
			TIM4->EGR= TIM4_EGR_UG;// update registers
			TIM4->CR1|= TIM4_CR1_ARPE | TIM4_CR1_URS |TIM4_CR1_CEN;// enable timer
			TIM4->IER= TIM4_IER_UIE;// enable TIM4 interrupt
			enableInterrupts();
			while(1)
			{
				if(tms%8000==0 && mean_sum!=tms/8000)
				{
				  setMatrixHighZ();
					mean_sum=tms/8000;
					if(mean_sum%4==3)
					{
						setWhite(11);
					}else{
						setRGB(4,mean_sum%4);
					}
				}
			}
		}
		case 9:
		{//dimness test with TIM2
			CLK->CKDIVR &= (u8)~(CLK_CKDIVR_HSIDIV);			// fhsi= fhsirc (HSIDIV= 0)
			
			GPIO_Init(GPIOD, GPIO_PIN_5, GPIO_MODE_OUT_PP_HIGH_FAST);
			GPIO_Init(GPIOD, GPIO_PIN_6, GPIO_MODE_IN_PU_NO_IT);
			UART1_DeInit();
			UART1_Init(1000000, UART1_WORDLENGTH_8D, UART1_STOPBITS_1, UART1_PARITY_NO, UART1_SYNCMODE_CLOCK_DISABLE, UART1_MODE_TXRX_ENABLE);
			//UART1_Init(1000000, UART1_WORDLENGTH_8D, UART1_STOPBITS_1, UART1_PARITY_NO, UART1_SYNCMODE_CLOCK_DISABLE, UART1_MODE_TXRX_ENABLE);
			UART1_Cmd(ENABLE);
			
			Serial_print_string("Mode: ");
			Serial_print_int(test_mode);
			Serial_newline();
			
			//run pwm interrupt at 2.000 kHz period (allow for >40 Hz frames with all LEDs ON)
			TIM2->CCR1H=0;//this will always be zero based on application architecutre decisions
			TIM2->PSCR= 5;// init divider register 16MHz/2^X
			TIM2->ARRH= 0;// init auto reload register
			TIM2->ARRL= 250;// init auto reload register
			//TIM2->EGR= TIM2_EGR_UG;// update registers
			TIM2->CR1|= TIM2_CR1_ARPE | TIM2_CR1_URS | TIM2_CR1_CEN;// enable timer
			TIM2->IER= TIM2_IER_UIE | TIM2_IER_CC1IE;// enable TIM2 interrupt
			enableInterrupts();
			while(1)
			{
				Serial_print_string("tms: ");
				Serial_print_int(tms/1000);
				Serial_print_string("tms2: ");
				Serial_print_int(tms2/1000);
				Serial_newline();
				setMatrixHighZ();
				setRGB(0,(tms>>11)%4);
				for(iter=0;iter<30000;iter++){}
			}
		}
		default:{}
	}
}

@far @interrupt void TIM4_UPD_OVF_IRQHandler (void) {
	TIM4->SR1&=~TIM4_SR1_UIF;
	tms++;
}

//millisecond interrupt
@far @interrupt void TIM2_UPD_OVF_IRQHandler (void) {
	TIM2->SR1&=~TIM2_SR1_UIF;//reset interrupt
	tms2++;
	//read buttons, update state
	//read audio, update state
}

//LED interrupt
@far @interrupt void TIM2_CapComp_IRQ_Handler (void) {
	TIM2->SR1&=~TIM2_SR1_CC1IF;//reset interrupt
	setMatrixHighZ();
	
}

//https://circuitdigest.com/microcontroller-projects/adc-on-stm8s-using-c-compiler-reading-multiple-adc-values-and-displaying-on-lcd
/*int ADC_Read(ADC_CHANNEL_TypeDef ADC_Channel_Number)
{
	int result = 0;
	ADC1_DeInit();
	ADC1_Init(ADC1_CONVERSIONMODE_CONTINUOU+S,
						 ADC_Channel_Number,
						 ADC1_PRESSEL_FCPU_D18,
						 ADC1_EXTTRIG_TIM,
						 DISABLE,
						 ADC1_ALIGN_RIGHT,
						 ADC1_SCHMITTTRIG_ALL,
						 DISABLE);
	ADC1_Cmd(ENABLE);
	ADC1_StartConversion();
	while(ADC1_GetFlagStatus(ADC1_FLAG_EOC) == FALSE);
		result = ADC1_GetConversionValue();
		ADC1_ClearFlag(ADC1_FLAG_EOC);
	ADC1_DeInit();
}*/

 void Serial_print_string (char string[])
 {

	 char i=0;

	 while (string[i] != 0x00)
	 {
		UART1_SendData8(string[i]);
		while (UART1_GetFlagStatus(UART1_FLAG_TXE) == RESET);
		i++;
	}
 }

 void Serial_print_int (int number) //Funtion to print int value to serial monitor 
 {
	 char count = 0;
	 char digit[5] = "";
	 
	 while (number != 0) //split the int to char array 
	 {
		 digit[count] = number%10;
		 count++;
		 number = number/10;
	 }
	 
	 while (count !=0) //print char array in correct direction 
	 {
		UART1_SendData8(digit[count-1] + 0x30);
		while (UART1_GetFlagStatus(UART1_FLAG_TXE) == RESET); //wait for sending 
		count--; 
	 }
 }

 void Serial_newline(void)
 {
	 UART1_SendData8(0x0a);
	while (UART1_GetFlagStatus(UART1_FLAG_TXE) == RESET); //wait for sending 
 }

void setMatrixHighZ()
{
	/*GPIO_Init(GPIOC, GPIO_PIN_7 | GPIO_PIN_6 | GPIO_PIN_5 | GPIO_PIN_4 | GPIO_PIN_3, GPIO_MODE_IN_FL_NO_IT);//2, 3, 4, 5, 6
	GPIO_Init(GPIOD, GPIO_PIN_3 | GPIO_PIN_2, GPIO_MODE_IN_FL_NO_IT);//0, 1
	GPIO_Init(GPIOC, GPIO_PIN_7 | GPIO_PIN_6 | GPIO_PIN_5 | GPIO_PIN_4 | GPIO_PIN_3, GPIO_MODE_OUT_PP_LOW_SLOW);
	GPIO_Init(GPIOC, GPIO_PIN_3 | GPIO_PIN_2, GPIO_MODE_OUT_PP_LOW_SLOW);*/
	GPIO_Init(GPIOC, GPIO_PIN_7 | GPIO_PIN_6 | GPIO_PIN_5 | GPIO_PIN_4 | GPIO_PIN_3, GPIO_MODE_IN_FL_NO_IT);//2, 3, 4, 5, 6
	GPIO_Init(GPIOD, GPIO_PIN_3 | GPIO_PIN_2, GPIO_MODE_IN_FL_NO_IT);//0, 1
}

void setRGB(int led_index,int rgb_index){ setLED(1,led_index,rgb_index); }
void setWhite(int led_index){ setLED(0,led_index,0); }

void setLED(bool is_rgb,int led_index,int rgb_index)
{
  const unsigned short rgb_lookup[10][3][2]={
		{{0,1},{0,2},{1,2}},//7
		{{1,0},{2,0},{2,1}},//3
		{{5,0},{5,1},{5,2}},//1
		{{6,0},{6,1},{6,2}},//20
		{{6,5},{6,4},{5,4}},//22
		{{4,3},{5,3},{6,3}},//23
		{{3,4},{3,5},{3,6}},//21
		{{0,5},{0,6},{1,6}},//19
		{{0,4},{1,4},{2,4}},//18
		{{0,3},{1,3},{2,3}} //2
	};
	const unsigned short white_lookup[12][2]={
		{3,0},//6
		{3,1},//4
		{3,2},//5
		{4,0},//14
		{1,5},//8
		{2,5},//9
		{4,1},//10
		{4,2},//16
		{2,6},//17
		{4,6},//12
		{4,5},//13
		{5,6} //11
	};
	bool is_low=0;
	do{
		GPIO_TypeDef* GPIOx;
		GPIO_Pin_TypeDef PortPin;
		switch(is_rgb?rgb_lookup[led_index][rgb_index][is_low]:white_lookup[led_index][is_low])
		{
			case 0:{
				GPIOx=GPIOD;
				PortPin=GPIO_PIN_3;
			}break;
			case 1:{
				GPIOx=GPIOD;
				PortPin=GPIO_PIN_2;
			}break;
			case 2:{
				GPIOx=GPIOC;
				PortPin=GPIO_PIN_7;
			}break;
			case 3:{
				GPIOx=GPIOC;
				PortPin=GPIO_PIN_6;
			}break;
			case 4:{
				GPIOx=GPIOC;
				PortPin=GPIO_PIN_5;
			}break;
			case 5:{
				GPIOx=GPIOC;
				PortPin=GPIO_PIN_4;
			}break;
			case 6:{
				GPIOx=GPIOC;
				PortPin=GPIO_PIN_3;
			}break;
			default:{
				
			}break;
		}
		GPIO_Init(GPIOx, PortPin, is_low?GPIO_MODE_OUT_PP_LOW_SLOW:GPIO_MODE_OUT_PP_HIGH_SLOW);
		is_low=!is_low;
	}while(is_low);
}

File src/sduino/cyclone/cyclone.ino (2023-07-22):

// Constants
const int NUM_LEDS = 10;         // Total number of LEDs
const int SPEED_INCREMENT = 100; // Speed increment when button pressed (in milliseconds)
const uint8_t TARGET_LED = 3;

// Variables
uint32_t start_ms = 0;                 // Start time of the current level
uint8_t current_led = 0;              // Currently cycling LED
uint16_t cyclone_speed = 1000;        // Speed of light movement (in milliseconds)
uint16_t initial_speed = 1000;
uint32_t delay_ms = 0;
int state = 0;
int H_BUTTON_PRESSED = 104;

void flush_leds(uint8_t led_count) {
  // pushes the temporary values live to the periphreal
}

void set_rgb(uint8_t index, uint8_t color, uint8_t brightness) {
  // led_index[0-9], color[0-255], brightness[0-255]
  Serial_print_s("index = ");
  Serial_print_u(index);
  Serial_print_s(" color = ");
  Serial_print_u(color);
  Serial_print_s(" brightness = ");
  Serial_print_u(brightness);
  Serial_println();
}

void reset_leds() {
  //sets all rgb+white LEDs to 0 brightness
  Serial_print_s("reset_leds()");
  Serial_println();
}

bool is_button_pressed(bool is_left, bool is_short) {
  // isButtonPressed(true,true); returns true if the left button is pressed
  // for 0.05-2 seconds.  (true,false) returns true if left button has been pressed for >2 seconds.
  // so bool is_right=isButtonPressed(false,true) || isButtonPressed((false,false); is expected here
  return true;
}

void handleButtonPress() {
  // using right button for cyclone; left is menu 
  if (is_button_pressed(false, true)) {
    // Check if target LED is active
    if (current_led == TARGET_LED) {
      // Increase difficulty by decreasing speed
      cyclone_speed -= SPEED_INCREMENT;
      if (cyclone_speed < 0) {
        cyclone_speed = 0;
      }
    } else {
      // Restart the game by resetting speed and start time
      cyclone_speed = initial_speed;
      start_ms = millis();
      reset_leds();
      flush_leds(10);
    }
  }
  state = 0;
}

void runCyclone()
{ 
  // Calculate delta time from level start
  uint32_t current_ms = millis();
  int32_t delta_time = current_ms - start_ms;

  if (current_ms - delay_ms >= cyclone_speed) {
     delay_ms = current_ms;
         
     Serial_print_s("delta_time = ");
     Serial_print_u(delta_time);
     Serial_print_s(" current_ms = ");
     Serial_print_u(current_ms);
     Serial_print_s(" start_ms = ");
     Serial_print_u(start_ms);
     Serial_print_s(" speed = ");
     Serial_print_u(cyclone_speed);
     Serial_println();
  
     // Compute position of the moving light
     uint8_t position = (delta_time / cyclone_speed) % NUM_LEDS;

     Serial_print_s("curr pos = ");
     Serial_print_u(position);
  
     // Update current LED
     current_led = position;
     uint8_t prev = position-1;
  
     // overflow protection
     if(prev > 9) prev = 0;

     Serial_print_s(" prev pos = ");
     Serial_print_u(prev);
     Serial_println();

     if (prev != TARGET_LED) {
        // turn off previous LED
        set_rgb(prev, 0, 0);
        set_rgb(prev, 0, 0);
        set_rgb(prev, 0, 0);
     }

     if (current_led != TARGET_LED) {
        // turn on current as GREEN
        set_rgb(current_led, 13, 255);
        set_rgb(current_led, 191, 255);
        set_rgb(current_led, 28, 255);
     }

     // Protection to make sure TARGET_LED 
     // stays lit as RED
     // Red is 255,0,0
     set_rgb(TARGET_LED, 255, 255);
     set_rgb(TARGET_LED, 0, 255);
     set_rgb(TARGET_LED, 0, 255);

     // Question for Scott
     // Do I need to flush only the LEDs I set here?
     flush_leds(NUM_LEDS);
  }
}

void readSerial()
{
   if (Serial_available() > 0) 
   {
      int inByte = Serial_read();
      Serial_print_i(inByte);
      // Letter h = 104
      if (inByte >= 104) {
         Serial_print_s("match");
         state = H_BUTTON_PRESSED;
         handleButtonPress();  
      }
   }
}

void setup() {
  // Initialize LED pins
  reset_leds();
  // Do this regardless when we go into Cyclone?
  flush_leds(NUM_LEDS);
    
  // Set initial start time
  start_ms = millis();
  // Used to know if we should cycle to next LED
  delay_ms = millis();
  
  // put your setup code here, to run once:
  Serial_begin(9600);
}

void loop() {
   readSerial();
   runCyclone();
}

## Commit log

2023-06-09 add documentation ideas
    [DC31_SAO_Insert.stl, costing.ods, dc31_badge_bottom.stl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]
2023-06-12 art outline
    [3d_print_acrylic_pcb_outlines_v1-BodyPocket001.stl, 3d_print_acrylic_pcb_outlines_v1.FCStd, 3d_print_lipo_402530_v1-BodyPad.stl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]
2023-06-22 v1r1 fab
    [BOM_PCB_Space_Pony_Prototype_1_2023-06-18.csv, PickAndPlace_PCB_Space_Pony_Prototype_1_2023-06-18.csv, costing.ods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]
2023-06-30 uart PD5 TxD to Ardunio pin 1 TX
2023-07-02 testing adc
2023-07-04 button test case
    [api_debug_04.stp, costing_v2.ods, pcb_layout_plan.ods]
2023-07-05 interrupt test
2023-07-07 notes abotu API functions
    [costing_v2.ods]
2023-07-09 morse draft in notes
    [pcb_layout_plan.ods]
2023-07-10 laser cut test v2
    [costing_v2.ods]
2023-07-11 laser cut test v4
2023-07-14 v6 laser cut
    [measuring_v2.FCStd, stl_assessment_v1-BodyPad_laser_cut.stl, stl_assessment_v1-BodyPad_shell.stl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]
2023-07-15 Add in DEFCON31 print out
2023-07-15 Patched up the serial printing and allowing for putty resizing
2023-07-16 preparing to work with TIM2
    [pcb_layout_plan.ods]
2023-07-16 application build serial print 1Mbaud
    [defcon31.stp]
2023-07-17 rgb race track
    [defcon31.stp]
2023-07-22 svg candidate files
    [BOM_PCB_Space_Pony_Prototype_1_2023-07-18.csv, DC31BADGE-CARD-OUTLINE_scaled_match_stl_pcb_outline.dxf, DC31BADGE-CARD-OUTLINE_scaled_match_stl_pcb_outline_hor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]
2023-07-22 3d print assembly rigs
    [assembly_rig_sticker_alignment_v1-BodyPocket005.stl, assembly_rig_sticker_alignment_v1.FCStd, assembly_rig_thru_hole_punch_v1-BodyPocket002.stl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]
2023-07-30 minesweeper implementation
    [defcon31.stp, empty.stp]
2023-07-30 Added winner.txt as binary Updated proto.ino to print WINNER
2023-07-31 minesweeper debugging
    [api_debug_04.stp, defcon31.stp]
2023-08-01 Fix missing bits on the winner byte array
    [proto.ino]
2023-08-02 added gate game and cleaned up dead code
    [costing_v2.ods]
2023-08-04 stable build
    [assembly_rig_sticker_alignment_v4-BodyPocket006.stl, assembly_rig_sticker_alignment_v4.FCStd, assembly_rig_thru_hole_punch_v2-BodyChamfer.stl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]
2023-08-07 clearn up readme add images
    [pcb_layout_plan.ods]
